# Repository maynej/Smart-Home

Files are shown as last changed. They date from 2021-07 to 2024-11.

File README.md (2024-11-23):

# Parc Mediambiental i Casa Domòtica Educativa

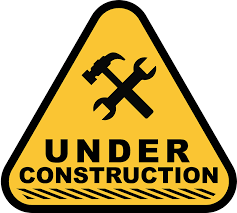
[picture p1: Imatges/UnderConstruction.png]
Parc Mediambiental en construcció 

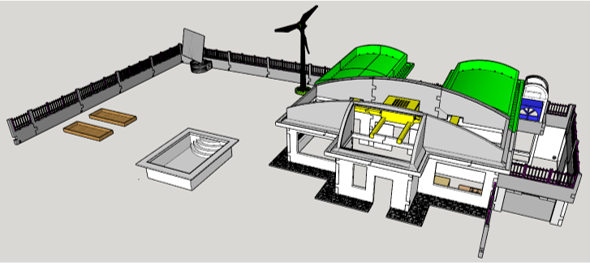
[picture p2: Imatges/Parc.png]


Casa Domòtica

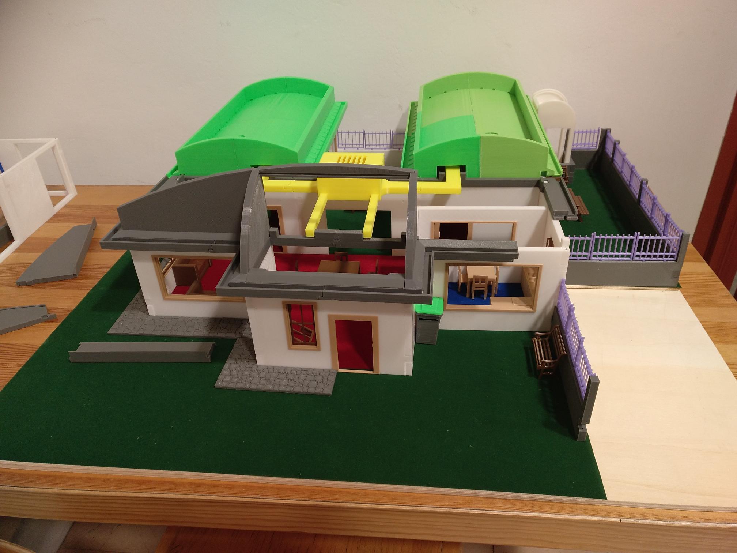
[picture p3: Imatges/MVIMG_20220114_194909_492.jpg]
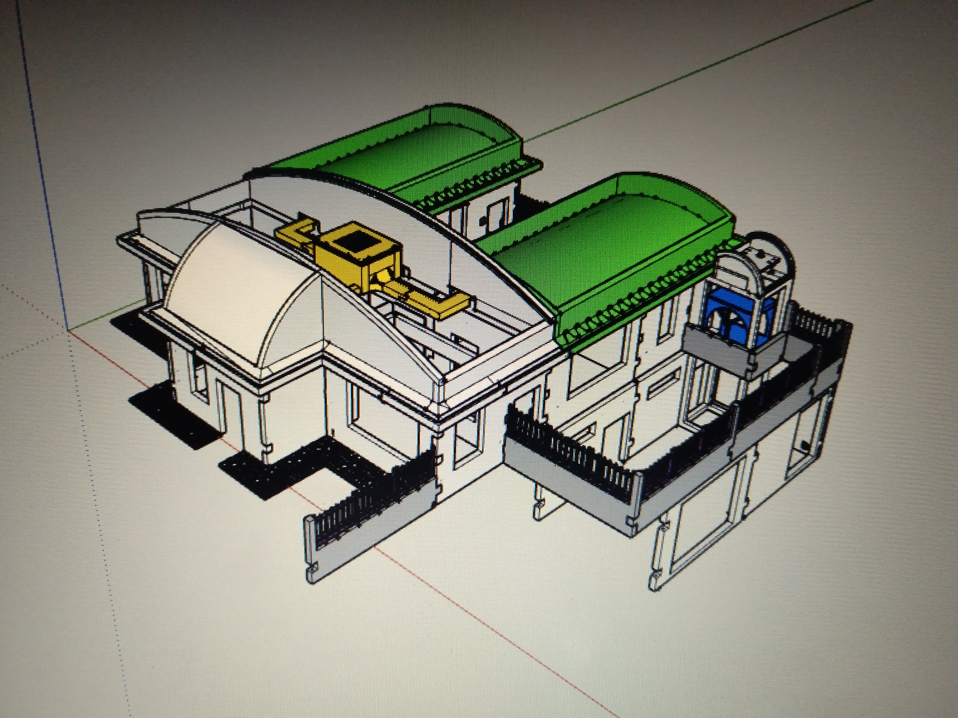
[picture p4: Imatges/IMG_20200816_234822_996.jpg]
 

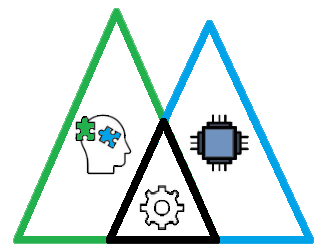
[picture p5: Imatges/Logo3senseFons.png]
Realitzada per [Jordi Mayné](https://github.com/maynej) des de Mechatronic Study jordi.mayne@mechatronicstudy.com 

L'objectiu es construir un parc mediambiental educatiu on estiguin representats espais del nostre entorn on vivim, arbres, hort, riu... i una casa sostenible aplicant la domòtica, gestionant el medi ambient i mesurant paràmetres de la natura.

Tota la [documentació es pot trobar en PDF](https://github.com/maynej/Smart-Home/tree/main/DOC). També en llengua castellana.

Un vídeo del muntatge de l'estructura de la casa el podreu trobar en la carpeta [Vídeos](https://github.com/maynej/Smart-Home/tree/main/Videos)

STL per imprimir [aquí](https://github.com/maynej/Smart-Home/tree/main/STL_SMARTHOME).

## Casa 3D 
  
Descripció         | Imatge          | Arxiu         
------------- | ------------- | ------------- 
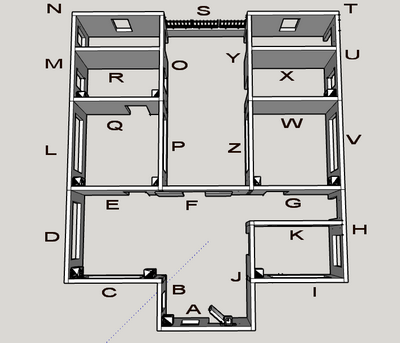
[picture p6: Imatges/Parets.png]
Parets | | [Parets](STL_SMARTHOME/Casa/Parets)
Finestres | | [Finestres](STL_SMARTHOME/Casa/Finestres)
Portes | | [Portes](STL_SMARTHOME/Casa/Portes)
Ascensor | | [Ascensor](STL_SMARTHOME/Casa/Ascensor)
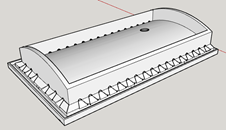
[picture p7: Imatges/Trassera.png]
Teulades |  | [Teulades](STL_SMARTHOME/Casa/Teulada)
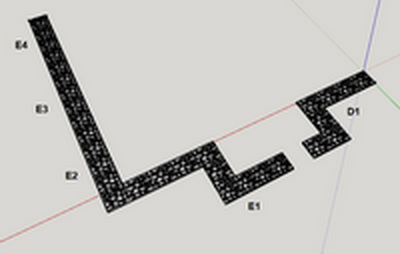
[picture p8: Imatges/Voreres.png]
Voreres | | [Voreres](STL_SMARTHOME/Casa/Vorera)
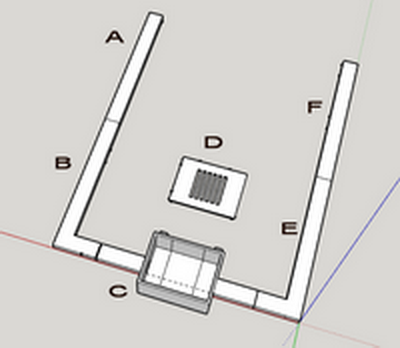
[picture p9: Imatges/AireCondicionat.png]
Aire Condicionat | | [Aire Condicionat](STL_SMARTHOME/Casa/AireCondicionat)
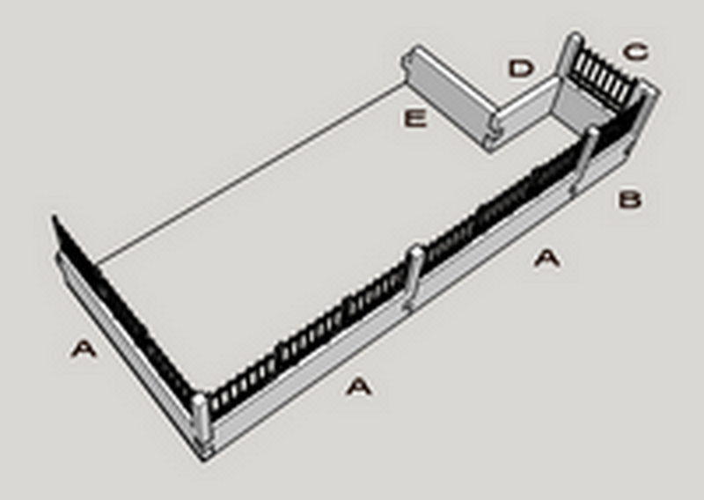
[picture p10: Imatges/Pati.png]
Pati | | [Pati](STL_SMARTHOME/Casa/Pati)

## Garatge

Descripció         | Imatge          | Arxiu         
------------- | ------------- | ------------- 
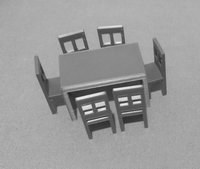
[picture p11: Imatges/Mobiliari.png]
Mobiliari | | [Mobiliari](STL_SMARTHOME/Casa/Mobiliari)

## Garatge

Descripció         | Imatge          | Arxiu         
------------- | ------------- | ------------- 
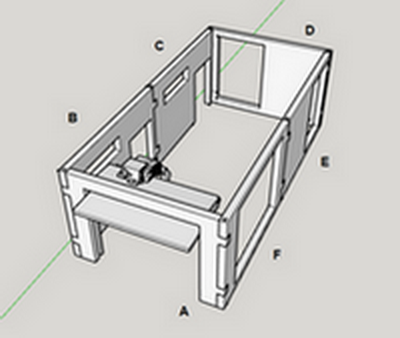
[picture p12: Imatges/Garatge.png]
Garatge | | [Garatge](STL_SMARTHOME/Garatge)

## Jardi (en contrucciò)

Descripció         | Imatge          | Arxiu         
------------- | ------------- | ------------- 
Generador Eòlic | | [GeneradorEolic](STL_SMARTHOME/Jardi/GeneradorEolic)
Seguidor Solar | | [SeguidorSolar](STL_SMARTHOME/Jardi/SeguidorSolar)

## Llicència

Creative Commons Attribution-NoComercial-ShareAlike 4.0 International (CC BY-NC-SA 4.0)  

## QR
<div id="qrcode">
Generador de Códigos QR Codes
<br/><a href="https://www.codigos-qr.com/en/qr-code-generator/" target="_blank" id"qrgenerator">Qr Code Generator</a>
</div>

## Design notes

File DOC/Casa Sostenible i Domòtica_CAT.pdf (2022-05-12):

1 | JORDI MAYNE ‐ 2022

# Parc mediambiental i casa domòtica sostenible

## Objectiu

Construir un parc mediambiental educatiu on estiguin representats espais del nostre entorn on vivim, arbres, hort, riu... i una casa sostenible aplicant la domòtica, gestionant el medi ambient i mesurant paràmetres de la natura.

## Dinàmica educativa

- Es pretén que sigui Obert, Didàctic, Evolutiu, Modulable, Flexible, i de baix cost.
- La construcció de la maqueta està preparada per ser impresa en una impressora 3D convencional, però, es pot fer amb fusta o cartró ploma, i al ser modular permet adaptar‐la a les necessitats.
- Permet gestionar els llums a LED de colors, Sensors, Actuadors y altres elements electrònics per tal fer la part domòtica i gestió que es podrà controlar amb un Arduino, Microbit o Rasberry ...

Com es podrà veure en tota la descripció, es vol que es puguin explorar el màxim tipus d’elements i tecnologies

## Descripció general

### Generació d’Energia

La generació d’energia es un dels punts d’estudi i aplicació en la maqueta: Eòlica, Solar, Tèrmica, Geotèrmica, Hidràulica

### Sensórica Externa

Mesurar paràmetres del nostre entorn ajudarà a gestionar‐lo, com la Temperatura i Humitat ambient, Humitat del sòl, Pressió atmosfèrica, Llum, Color, Raigs ultraviolats, Qualitat del aire i aigua, Nivells d’aigua, Velocitat i direcció del vent, Partícules en el aire.

### Casa Domòtica

Control del màxim d’elements fent servir tecnologies diverses com la Llum, Accés, Tendal, Ventilació, Calefacció, Motors, Vàlvules, Intrusió, Panells Fotovoltaics, Tèrmics, Acumuladors energia.
Es detectarà Gas, Foc, Llum, So, Humitat, Temperatura ambient, Temperatura del aigua, Presencia (PIR, IR), Alarma, Intrusió.

### Comunicacions

Dintre d’un entorn sostenible les comunicacions son necessàries si es gestionen be com Bluetooth, Wifi, Ethernet, RFID

## Realització del projecte

- Descripció de cada part de la maqueta.
- Selecció de materials i components.
- Desenvolupament de cada part.
- Construcció de la maqueta.
- Composició del control electrònic.
- Control global de la maqueta.

### Maqueta

La maqueta es divideix en dues parts, una es la Casa pròpiament i l’altre el seu entorn que l’anomeno Parc, degut a les dimensions de la mateixa, uns 80x85cm cada part. Això comença a definir la modularitat d’aquest projecte. Seguidament es descriu cada una de les parts.

## Parc mediambiental

### Estació Meteorològica

- Peces fetes amb una impressora 3D ja dissenyades a Thingiverse, hi ha moltes possibilitats.
- No podrà tenir unes dimensions proporcionals a la maqueta de la casa per la pròpia física.
- Estarà situada en la part oposada a la casa per millorar la seva perspectiva.
- Comunicarà via radio (Wifi o Bluetooth) amb la central de control de la casa, on una pantalla mostrarà totes les dades.

(Estació metereológica)

Opció 1: Mòdul GY‐39 Intensitat de llum MAX44009 + BMP280 Temperatura, Humitat, Pressió

Opció 2: GY‐30 (Intensitat llum) o GY302 o GY‐49 (Intensitat llum) MAX44009,
BMP280 (Pressió, Temperatura), DHT11 (Humitat, Temperatura) Mòdul Wifi ESP 32

Velocitat del vent (contactes reed + imant)
Direcció del vent (reed + imants) Pluviòmetre (reed + imant)

### Hort i Arbres

Un recipient ple de terra farà d’hort, es mesurarà la humitat de la terra i juntament a la temperatura i la llum es programarà el regadiu.

(Hort)

### Generació d’energia

Panell Foto‐voltaic amb seguidor solar per generar electricitat
- https://www.thingiverse.com/thing:4056888
- Cèl∙lula Solar 5V
- Motors servo MG90.
- Cèl∙lula LDR | (Panell Solar)

Panell Tèrmic per escalfar aigua
- Tub en espiral formant un panell solar, anirà en el terreny del costat de la casa.
- L’aigua calenta entra en un dipòsit acumulador de la casa
- Sensor de temperatura
(Panell Tèrmic)

Aprofitament Geotèrmic
- Tub en espiral sota terra amb una Peltier per simular el comportament subterrani
- Tub en espiral en el terra de la casa
- Sensor de temperatura | (Aprofitament Geotèrmic)

Generador Eòlic per generar electricitat
- https://www.thingiverse.com/thing:1767153
- Dinamo: motor dc 15.2 x 19.8 mm, rotor 2 mm.

(Generador Eòlic)

Generador Hidràulic per generar electricitat
- Un dipòsit superior configura un canal d’aigua fins un salt on fa moure les pales del generador, segueix l’aigua a un petit llac, que deriva a un canal més petit per regar el hort i arbres.
- https://www.thingiverse.com/thing:802284
- Salt d’aigua amb dinamo: motor dc 15.2 x 19.8 mm, rotor 2 mm.
(Turbina d’aigua)

Casa Sostenible i Domòtica • Les noves cases han de ser sostenibles, aprofitant totes les energies renovables que estiguin a l’abast

(eòlica, tèrmica, solar, hidràulica, geotèrmica).
- Recollida de l’aigua pluvial per reaprofitar‐la.
- Aprofitament de la llum solar i el vent.
- Aïllament amb un sostre verd.
- Control de residus.
- Control domòtic.

### Disseny de la maqueta de la casa

Per fer la maqueta vaig buscar idees i maquetes fetes amb impressió 3D. Només vaig trobar a Thingiverse aquesta https://www.thingiverse.com/thing:2364628 que em va semblar una bona forma d'assemblar les parets i les dimensions (escala 1:24), per poder incloure i manipular els actuadors, encara que l’he transformat i adaptat a les necessitats buscades.

(1)

La maqueta s’ha dissenyat per cobrir totes les necessitats per aplicar tecnologia. Primer dibuixant tota la casa , que al final te unes dimensions importants 850x800mm i desprès feta a trossos per poder‐la imprimir en una impressora 3D convencional de 200x200mm i d’aquesta manera es pot tractar de forma modular i realitzar amb els mateixos mòduls altres tipus de configuració de la casa. També incorporen les fixacions dels actuadors a les portes, finestres, i allotjaments dels llums. La teulada es pot treure molt fàcilment per mirar i accedir a l’interior de la casa.

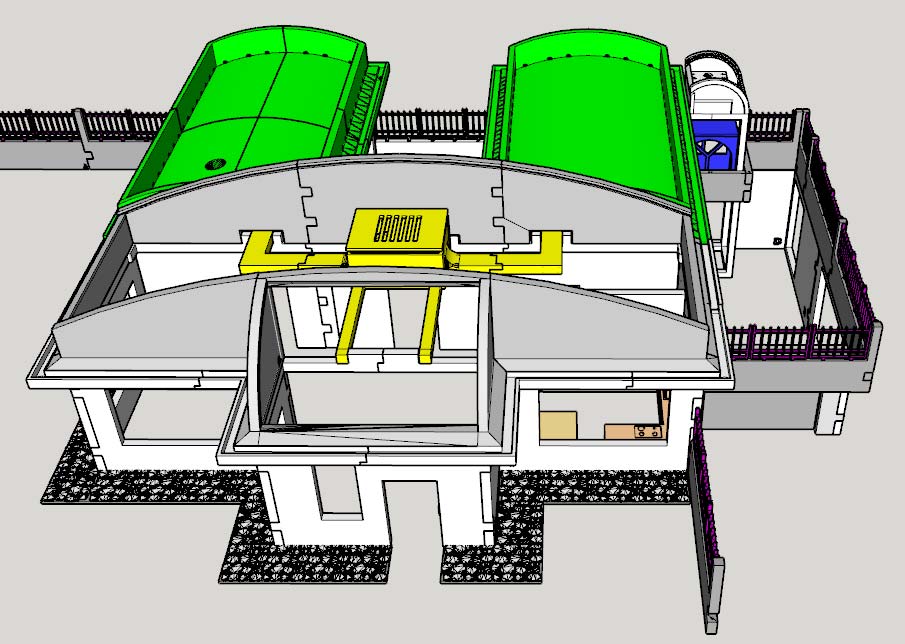
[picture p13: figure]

(2)

### Identificació i unió de les peces de la maqueta

- Per fer la maqueta s’ha buscat un sistema d’identificació de cada peça, marcant amb una lletra cada paret o mur per un construcció guiada i més fàcil.
- La unió entre les peces s’han dissenyat per que no estigui que fer servir cap cola en la majoria de les peces. Aquesta unió està feta a base d’encaixos i un passador que les fixe.

## Descripció de l’exterior Casa

- Casa de tipus unifamiliar que sigui accessible per manipular els diferents components.
- Porta per vehicles exterior motoritzada per anar al garatge. Accés via Bluetooth.
- Porta d’accés a la finca. Timbre, i Accés amb identificació RFID.
- Il∙luminació autònoma a LED, amb detecció de presencia i de llum diürna.

### Porta d’entrada de vehicles

Porta lliscant amb accés remot via Bluetooth per identificar i obrir.

- Mecanisme cremallera amb servo‐motor de 360 graus MG995.
- Identificació via Bluetooth HM10 o Wifi relé ESP8266
- Llum de senyalització de moviment de porta APA106 o WS2812.
- Verd detecció ID Bluetooth
- Ambre moviment porta
- Vermell Identificació invàlida
- Detecció d’obstacles de seguretat amb IR TCRT5000 | o HCRS04 .

### Porta d’accés a la finca

Com qualsevol casa un polsador servirà de timbre, també un lector RFID identificarà i permetrà obrir la porta amb una targeta RFID vàlida.

- Timbre de trucada amb polsador
- Lector RFID RC522
- Porta motoritzada amb Servomotor SG90

### Il∙luminació exterior de la casa

Llums LED de color WS2812 i un sensor de proximitat PIR HC‐SR501 amb sensor de llum diürna per il∙luminar la porta d’entrada o les permanents de nit des del control central.

### Dipòsit d’aigua pluja

L’aigua de pluja es recull des de la teulada de la casa, s’emmagatzema en un dipòsit intern per fer servir per lavabos, dutxa, wc, rentadora.

- El sistema de control de bombeig.
- Control de nivell dipòsit d’aigua.

## Descripció de l’interior de la Casa

- Control d’accés portes exteriors
- Sistema d’alarma
- Control de llum LED individualitzat amb intensitat i color
- Guia llum solar recolzada amb LED
- Control finestres batents motoritzades
- Control de portes motoritzades
- Control Ventilació, Calefacció, Refrigeració
- Ascensor
- Tendals motoritzats

### Porta d’accés a la casa

- Lector RFID RC522 | Lector Empremta dactilar
- Servo SG90

### Llum interior de la Casa

El control de la llum tant es fa manualment, com automàtic mitjan sensors.

- LED + Detector IR per passadissos HC‐SR501
- LED + Interruptor sensitiu per saló TTP223
- LED + Sensor de veu per la despensa
- Led + Sensor de llum ambiental TEMT6000 | o LDR

### Guia llum solar

Cilindre de metacrilat guia la llum solar en el interior de la casa, per la nit un llum LED fa la funció solar

(6)

(5)

### Control de tendal

- Tendal o Persiana, Sostre motoritzat
- Motor pas a pas K976
(7)

### Aire Condicionat

Un sistema central d’aire condicionat format per una cèl∙lula Peltier genera calor o fred per inversió de polaritat, i un ventilador mou l’aire per tota la casa

- Temperatura LM35 | o DS18B20
- Ventilador + Peltier (Refreda/Escalfa)

### Sistema d’Alarma

Un sistema integrat d’alarma contra intrusió, foc, gas

- Sensor de vibració SW‐520D
- Contactes amb imants a finestres
- Sensor de gas MQ‐2
- Sensor flama
- Brunzidor

### Pantalles de control

- Pantalles Oled o LCD, on es distribuirà la informació per treballar per àrees. També es podrà tindre accés des de un telèfon o “tablet”.
- Monitorització de dades de l’estació meteorològica.
- Monitorització del control d’accés a la casa, garatge, sistema de seguretat.
- Monitorització de la refrigeració, ventilació, calefacció
- Monitorització del ascensor.

### Sistema central de control

El control també està pensat obert, si no ja no seria didàctic. Tots els actuadors i sensors poden estar adaptats a les plataformes més utilitzades com Arduino, ESP32, Microbit o Raspberry.

El software d’aquestes plataformes permeten utilitzar diferents llenguatges de programació, Scratch, C++ per Arduino, ArduinoBlocks, MakeCode, Python entre d’altres.

- Arduino, ESP32: Scratch, Arduino Blocks, C++
- Microbit: MakeCode, Python, C++
- Raspberry: Python, Java, Linux

Alimentació i bateries.

La maqueta al igual que moltes cases actuals que generen energia per el autoconsum, necessiten també d’energia elèctrica addicional. La maqueta tindrà generadors d’energia que carregaran unes petites bateries i també tindrà un font d’energia addicional.

Plantejament de la casa Com que no soc arquitecte segur que no he fet una casa "bonica“, ni arquitectònicament correcte, però tinc

la sort de tenir amistats arquitectes que m’han ajudat a fer algunes correccions.

El que busco es aplicar diferents tecnologies per fer una casa sostenible, aprofitant les energies renovables i fer conscienciació dels nostres elements que ens envolten.

El garatge sota terra es justifica per poder tenir un ascensor amb el seu control. I a més poder tenir sota la casa el cablejat de control totalment manipulable, el dipòsit de recollida d'aigua de pluja i el dipòsit tractament d'aigües blaves.

L'accés als dispositius tant de la casa com a la resta del entorn es accessible, per poder veure o canviar els sensors, actuadors o sistema de control de qualsevol racó.

## Plantejament del control

- El control es podrà fer a través de tasques individualitzades o agrupades junt amb la pantalla o pantalles per mostrar els seus funcionaments o/i amb un control central per recollir el funcionament global.
- Moltes tasques es faran simulades intentant reproduir al màxim el seu funcionament real.
- Els sensors bàsics utilitzats es podran canviar per altres més cars o sofisticats, està previst que el seu accés i cablejat ho permeti.
- Els actuadors seran alguns diferents per provar totes les tecnologies.

Aquest apartat es mostrarà al final de la construcció de la maqueta

### Maqueta interior casa

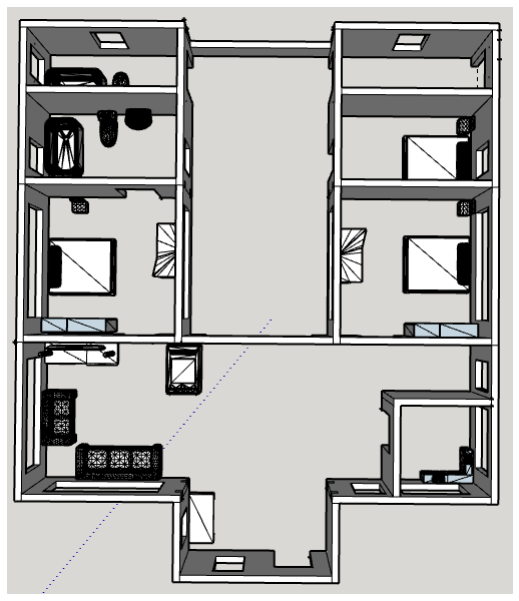
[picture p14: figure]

(8)

### Maqueta Casa, Garatge i Pati

El pati està a sobra del garatge i deixa un espai per el pas del ascensor.

### Maqueta Garatge i Ascensor

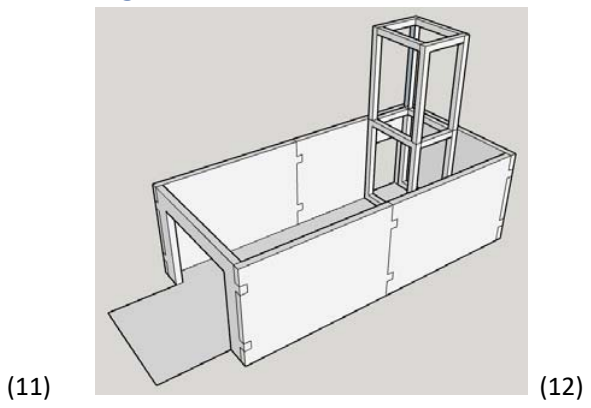
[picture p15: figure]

Detall del mecanisme de la porta de garatge

(13)

### Ascensor

L’ascensor te dues plantes. Permet accedir a la casa des del garatge.

- Un motor pas a pas en la part superior proporciona un desplaçament precís i lent. 28BYJ‐48 DC 5V
- La cabina te dues guies, una llisa i una amb rosca M4

(14)

### Finestres batents i Portes motoritzades

- Les finestres son batents amb moviment a través d’un servo‐motor.
- Les portes també estan motoritzades a través d’un servo‐motor.
- Totes les portes i finestres tenen els ancoratges en la paret per posar un servo‐motor.

### Aire Condicionat

- Una màquina en el saló distribueix l’aire, aire fred i aire calent.
- Un ventilador de 40x40x10 impulsa aire que passa per una cèl∙lula Peltier. Canviant la polarització de la Peltier produeix fred o calor.
- Els tubs condueixen cap a totes les estàncies.

(16)

### Teulada

La teulada està formada per tres parts, la frontal i els dos posteriors. Amb una base amb els canals de desguàs del l’aigua pluvial, i per la part de sota incorpora els espais on aniran instal∙lades les llums externes a LED.

- Teulada Frontal
La teulada frontal serà transparent i amb una
coberta interior tèxtil motoritzada per aïllament
tèrmic.
Permet observar l’interior del menjador/sala i cuina

(17)

- Teulada Verda
La teulada verda dels dos laterals permeten drenar l’aigua i formar un aïllament tèrmic, així com un entorn visual millor.

Per sota hi ha els allotjaments dels llums d’habitacions i exteriors, i el canal dels fils, perquè es pugui treure la teulada de la maqueta per accedir a l’interior.
El forat rodó permet instal∙lar un guia llum.

(18)

La coberta de la teulada estarà coberta de verd, amb plantes i diferents capes de materials que permeten un aïllament de la casa i drenar l’aigua de pluja.

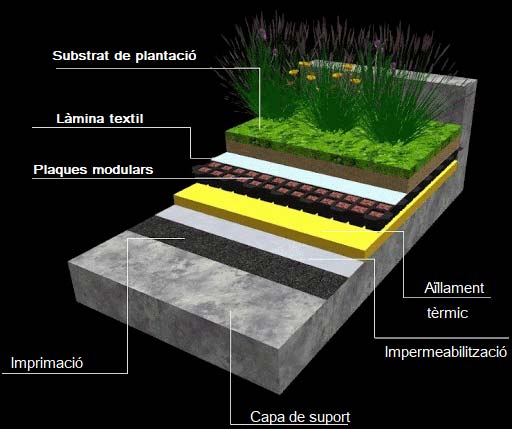
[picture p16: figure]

(19)

- Teulades a la maqueta

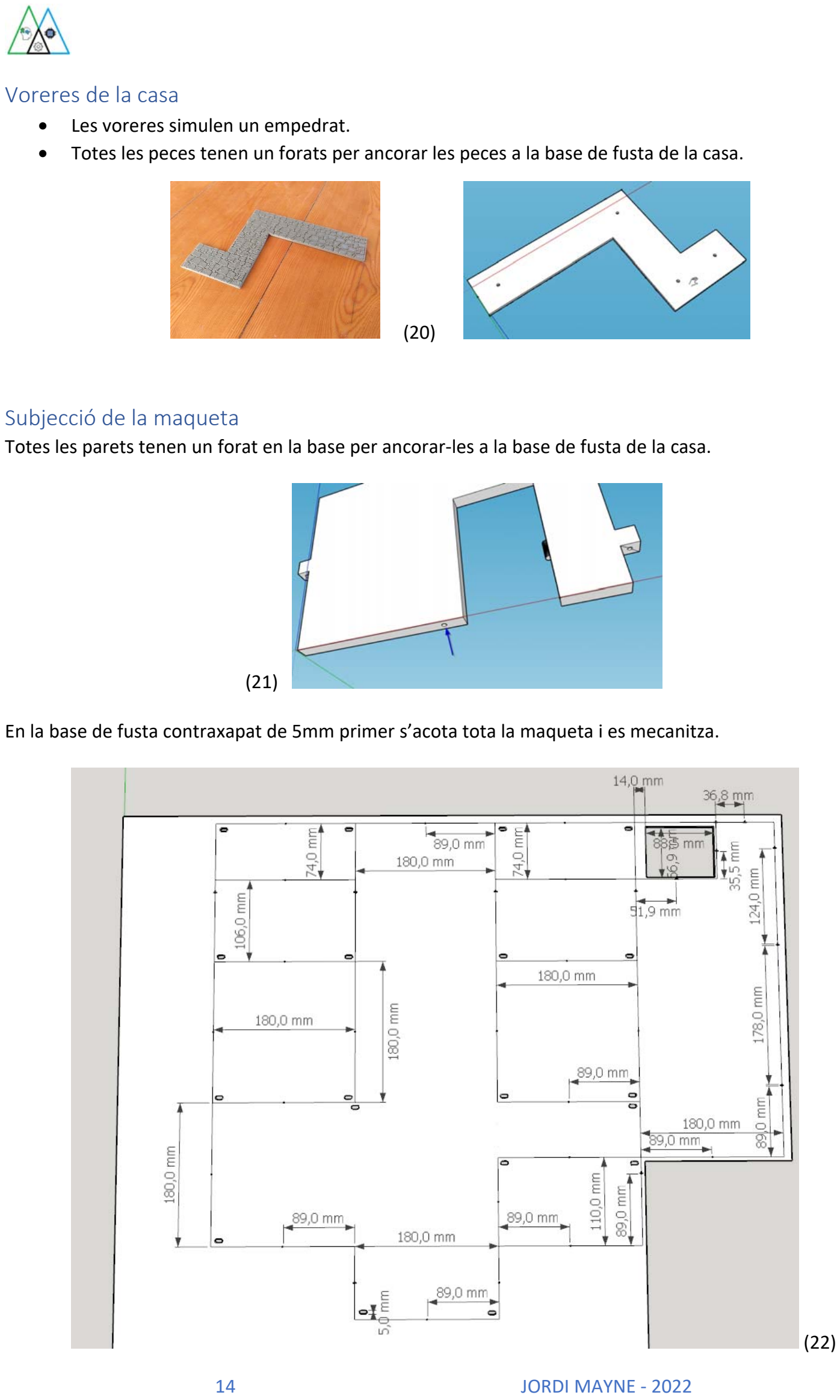
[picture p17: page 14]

### Voreres de la casa

- Les voreres simulen un empedrat.
- Totes les peces tenen un forats per ancorar les peces a la base de fusta de la casa.

(20)

### Subjecció de la maqueta

Totes les parets tenen un forat en la base per ancorar‐les a la base de fusta de la casa.

(21)

En la base de fusta contraxapat de 5mm primer s’acota tota la maqueta i es mecanitza.

(22)

Abans de fixar‐la s’aprofita per emmoquetar el terra del interior i la gespa del exterior.

Seguidament ja es pot fixar la maqueta

Ara ja es pot continuar treballant amb la resta de la casa, posant els marcs de les portes, finestres, ....

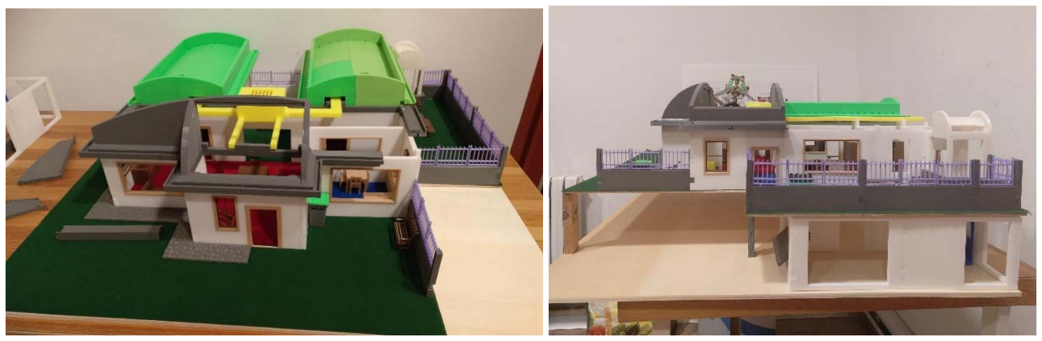
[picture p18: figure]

El tauler base de la casa es pot muntar sobre un altre tauler de 10mm contraxapat, separat per columnes de 120mm d’alçada, que es la mida exacte del garatge. Aquest espai servirà per col∙locar l’alimentació, bateries, electrònica, displays, lectors RFID i lector dactilar, etc ...

La teulada semi‐transparent es pot fer amb full de plàstic a partir de 0,75mm de gruix per que tingui una mica de consistència. S’ha de tallar per la teulada frontal 176x132mm i la per la teulada del saló/menjador/cuina amb dos trossos de 176x290.

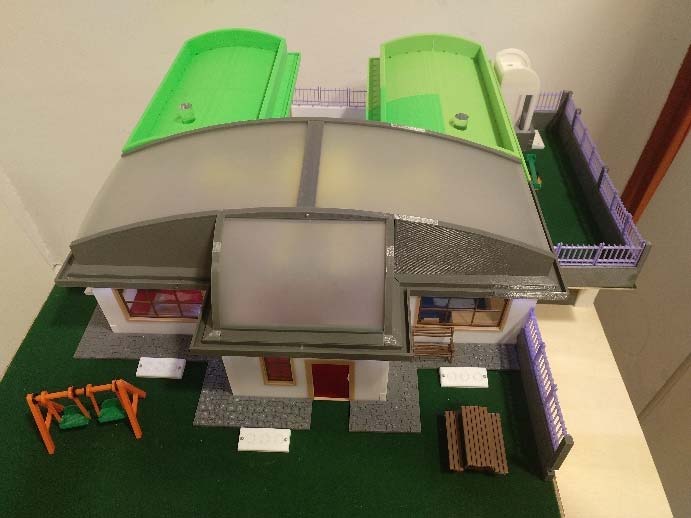
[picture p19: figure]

### Muntatge electrònic

Per començar amb el sistema electrònic es pot fer el connexionat dels llums de LED multicolor WS2812B en la part posterior de les teulades. Fent servir tres fils (Positiu 5V,
negatiu (gnd) i dades) amb tres color ben diferenciats per no fer cap errada, es poden fixar
els fils trenant en forma d’espiral i subjectats amb tub termo‐retràctil.

Les soldadures han d’estar ben fetes i que no puguin creuar les connexions, cal fer una revisió visual abans de col∙locar‐lo als encaixos de la teulada i una prova de funcionament.

Una vegada que es te el cablejat fet, es col∙loca en la guia corresponent i es fixe amb una mica de cola termo‐ fusible.

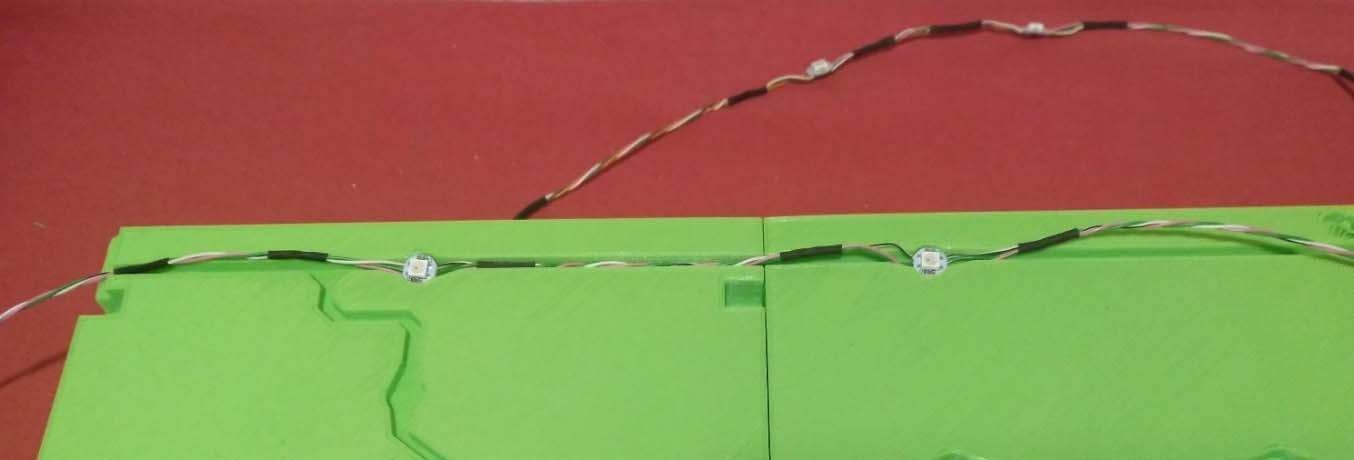
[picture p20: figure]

## Plantejament del control

Tal com està exposat al principi d’aquest document, el control es podrà fer a través de tasques individualitzades o agrupades per facilitar una programació primerament per parts i també per facilitar l’ús de un hardware senzill. D’aquesta manera es poden establir funcionalitats bàsiques fins les més complexes, i funcionalitats futures.

### Tasques individualitzades

En aquest apartat es mostraran les tasques que es poden realitzar per treballar‐les individualment i el seu hardware associat.

### Control dels llums de la casa

Els llums de la casa son de LED del tipus RGB WS2812, que permeten encendre amb el color que es vulgui (per programa), així com amb la intensitat de llum desitjada. Això permet també fer escenaris diferents sobre tot amb la il∙luminació exterior. I en el interior també poder fer servir per fer un ambient més càlid per les habitacions o més fred com potser la cuina. Aquets llums poden ser automàtics com el cas dels llums exteriors, amb un sensor de llum ambient, o a través de polsadors tàctils a cada habitació. També es podrà comandar algun llum amb sensor de presencia, com pot ser en el passadís de l’ascensor, ascensor i garatge. Per tant si es fa flexible la instal∙lació d’elements de control donarà més marge d’usar més mitjans de control i de futures idees.

Primer de tot cal enumerar cada punt de llum de la casa.

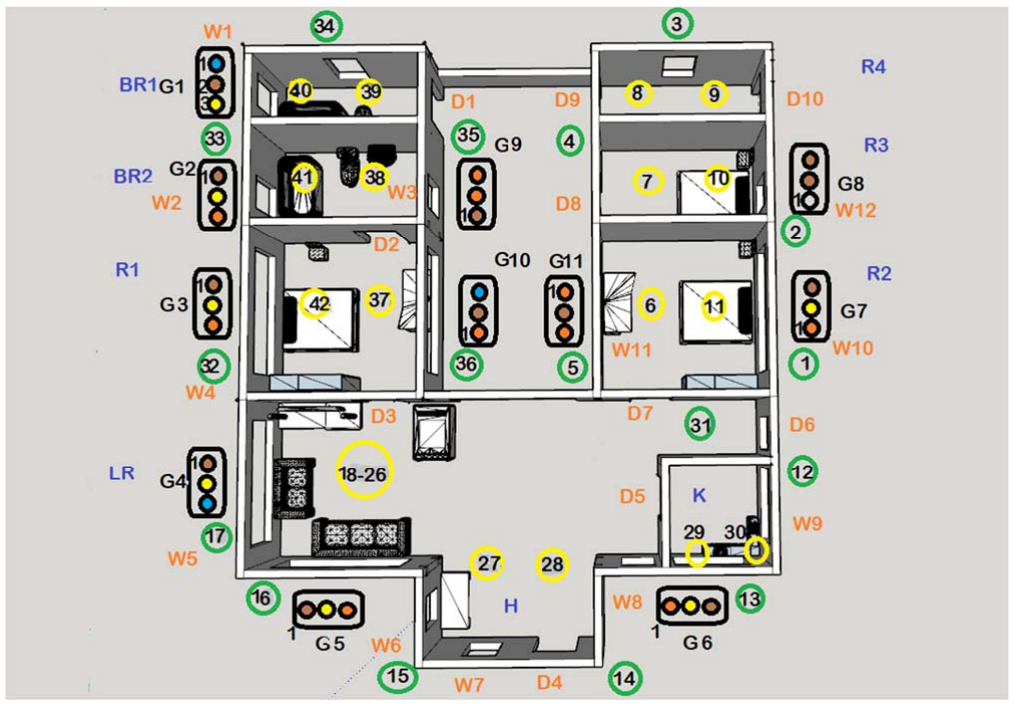
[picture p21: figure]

Els cercles de color verd son els llums d’exterior de la casa, que normalment es faran encendre tots a la vegada i amb el mateix color tots, però es podran programar escenes amb diferents colors e intensitats de llum. En color verd també hi han els llums externs, però, de
la terrassa interior, aquest agrupament es pot fer separadament dels altres amb un color
fixe. Els cercles de color groc son part de la il∙luminació interior, saló‐menjador, cuina,
dormitoris banys i passadissos. Aquests llums tenen els punts d’encendre senyalitzats com a G1, grups de 3 polsadors que poden actuar com polsador o interruptor numerats com G1_1, G1_2, G1‐3. També es faran servir aquests polsadors tàctils per obrir i tancar finestres com W1 o portes com D1. Finalment també s’enumeren els espais com BR1, BR2, R1...

Tots aquests punts de llum a LED van connectats en sèrie en el ordre indicat de numeració, i s’utilitzen 3 fils (positiu, negatiu i dades), aquets fils aniran connectats a la placa de control que es posi (ja sigui Arduino, Microbit,...) i fa que només ocupi un pin de sortida.

### Polsadors/Interruptors

En la maqueta hi ha punts de polsadors per activar llums, servos, aquests polsadors son tàctils utilitzant el TTP223, un circuit que permet diverses maneres de treballar, com un polsador, com un interruptor. Encara que te altres funcionalitats.

Les particularitats d’aquest circuit que es mostra en l‘esquemàtic, es que pot alimentar entre 2,5 a 5Vdc i directament entrega un estat de sortida depenent de les connexions dels pins A i B, un LED indica l’estat de sortida.

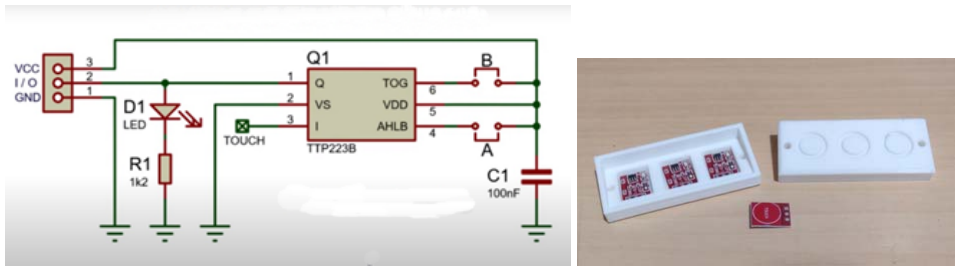
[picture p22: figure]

Connexionat | Acció
Sense B | Polsador
Pont B | Interruptor
Pont A | Nivell alt per defecte

El connexionat del polsador tàctil tindrà una connexió del pont B, per tenir funcionalitat Polsador o Interruptor segons el vulgui programar. Estarà disponible en la part inferior de la casa un connector pont.

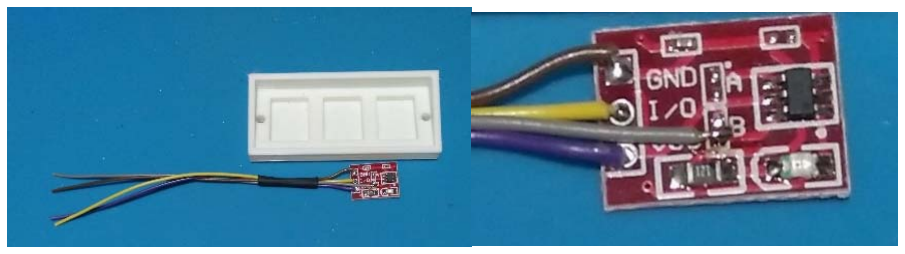
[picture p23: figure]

Així quedaria el connexionat amb la placa Arduino, però ja es veu que utilitza molts pins d’entrada.

### Expansió d’entrades i sortides en un Arduino

Com que es necessiten moltes entrades de polsadors els llums i servos, cal plantejar utilitzar varies plaques Arduino, cosa que no es la solució més adequada. Es millor col∙locar un expansor d’entrades que es pot fer amb un mòdul placa multiplexor analògic o amb un mòdul expansor I2C.

74HC4067 multiplexor de 16 canals, s’alimenta entre 2,5V a 6V, permet fins a 16
canals (C0 a C15) d’entrada o sortida i es necessiten 3 senyals de control (S1 a S3),
dos pins alimentació, un de Enable.

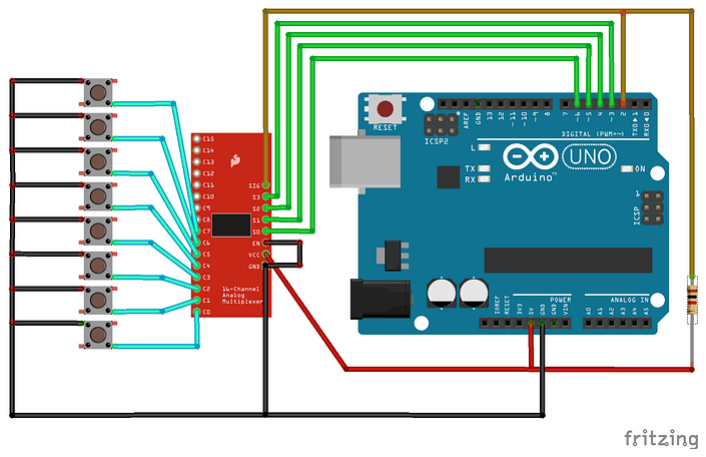
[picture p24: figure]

Però, no es la millor solució en quan a consum i número de fils cap al microcontrolador.

Una solució més avançada es utilitzar un circuit que es comunica amb el microcontrolador amb 2 fils, via I2C.

PCF8574 es un expansor de 8 canals digitals de entrada/sortida amb comunicació I2C cap el microcontrolador, per defecte al alimentar el circuit son entrades digitals (P0 a P7), funciona entre 2,5 i 6V, incorpora 3 pins (A0 a A2) per configurar l’adreça I2C (des de 0x20 a 0x27), te dos pins de comunicació típiques de I2C, SDA (dades), SCL (rellotge) i un pin INT (interrupció) que es posa a nivell 0 quan hi ha un canvi de flanc en algunes de les entrades/sortides del xip, això permet no tenir que rastrejar constantment els pins d‘entrada per part del microcontrolador.

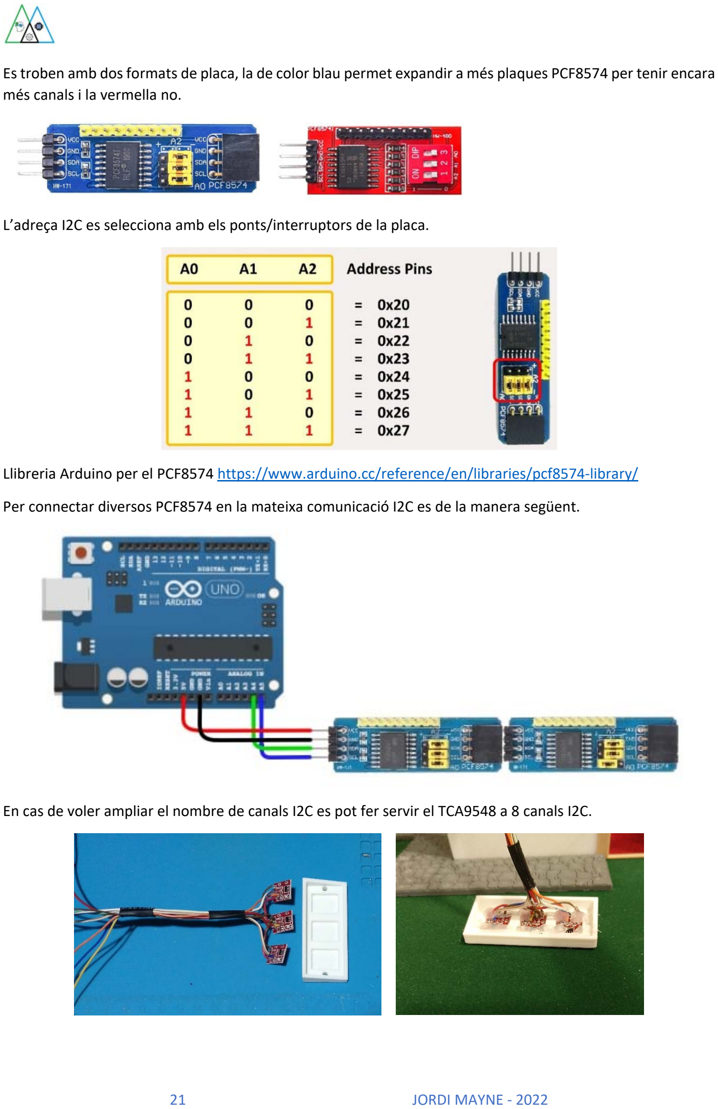
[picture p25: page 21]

Es troben amb dos formats de placa, la de color blau permet expandir a més plaques PCF8574 per tenir encara més canals i la vermella no.

L’adreça I2C es selecciona amb els ponts/interruptors de la placa.

Llibreria Arduino per el PCF8574 https://www.arduino.cc/reference/en/libraries/pcf8574‐library/

Per connectar diversos PCF8574 en la mateixa comunicació I2C es de la manera següent.

En cas de voler ampliar el nombre de canals I2C es pot fer servir el TCA9548 a 8 canals I2C.

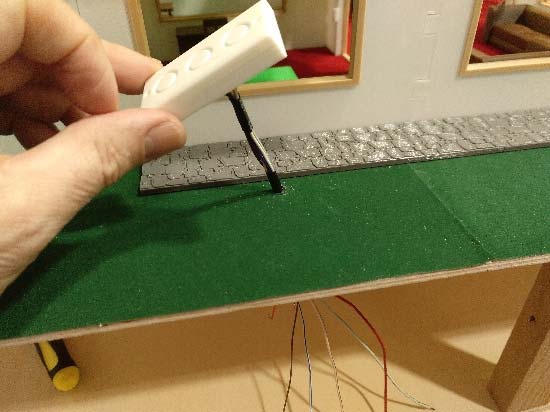
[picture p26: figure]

Es pot observar que a través de la coberta de plàstic es pot veure la llum vermella de actuació del tàctil.

### Control de 16 servomotors en un Arduino

Com que es necessiten moltes sortides per tots els servomotors de control de portes i finestres; Arduino només disposa de 6 sortides PWM, per el que cal utilitzar varies plaques, però, no es la solució més adequada. Es millor utilitzar una placa PCA9685 connectada via I2C amb el microcontrolador.

A més els servomotors tenen un consum elevat, sobre els 200mA multiplicat per 16 son 3,2A

PCA9685 suporta fins a 16 servomotors controlats via I2C, disposa del
pins per connectar adequadament els servomotors, les adreces I2C
van des de 0x40 fins a 0x7F soldant els ponts (A0...A5), entrega 16
sortides PWM de 12 bits, s’alimenta a 5V, i les línies SDA i SCL de I2C son compatibles 3V3 o 5V.

Servomotors SG90

Un servomotor o anomenat també servo, és un motor DC amb la capacitat posar el seu eix en una posició o angle determinat, internament té una caixa d’engranatges reductora que fa augmentar el parell motor i redueix la velocitat, un potenciòmetre està encarregat de sensar la posició de l’eix i junt amb una electrònica formen un control de llaç tancat.

Hi ha diferents tipus de servo‐motors, el més utilitzat es el SG90 que es suficient per la majoria d’aplicacions. Funciona entre 3 i 7.2V, te un parell motor entre 1 i 1.6 kg/cm. Altres tenen parells motor més grans arribant fins a 15 kg/cm.

Base per programar els servomotors

https://www.luisllamas.es/controlar‐16‐servos‐o‐16‐salidas‐pwm‐en‐arduino‐con‐pca9685/

Informació per més coneixement sobre els Servomotors:

https://dronprofesional.com/blog/tutorial‐teorico‐practico‐con‐servos‐y‐arduino/

Esquemàtic de control de llums i servos

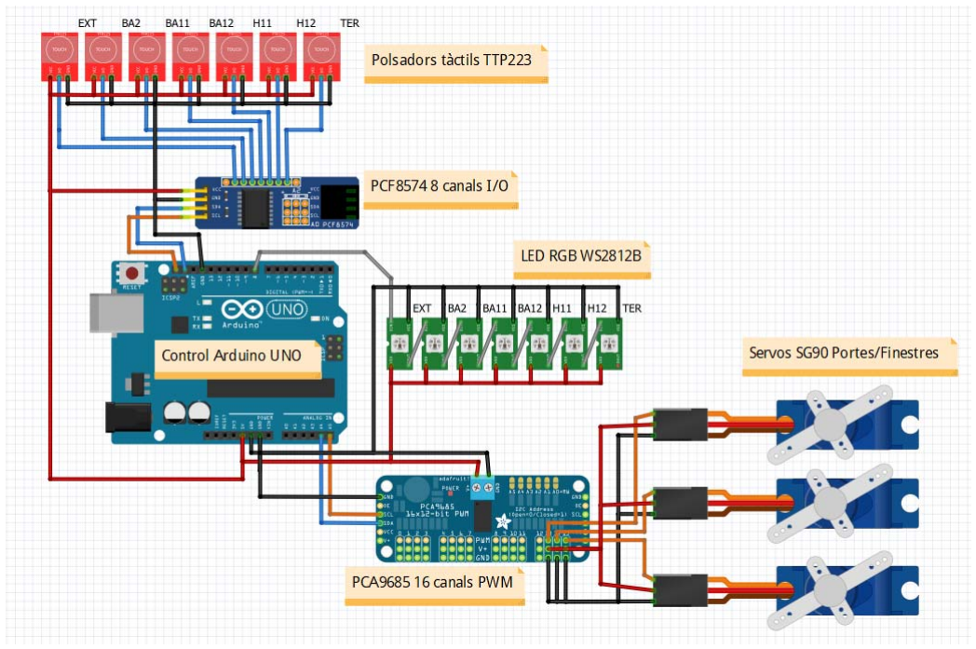
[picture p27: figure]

Muntatge del servo motor en un suport i la fixació a la paret d’una finestra i d’una porta.

### Sensor de llum ambient

De sensors de llum hi ha diverses possibilitats: el TEMT6000 que només detecta la presència amalgamada de llum amb longituds d'ona en el rang de 390 a 700 nm. Es troba amb formats molt petits, com el Lilypad o format rectangular per poder‐lo fixar.

Lilypad | Rectangular

El TSL2561 es un sensor de lluminositat que pot detectar tant la llum visible com la llum infraroja. El ISL29125 es un sensor de llum RGB que pot detectar llum específicament vermella, verda, blava o qualsevol combinació d'aquestes. El ML8511 es un sensor de llum U,V funciona de manera similar al TEMT6000, però respon a la llum ultraviolada en lloc de la llum visible. El LDR és una alternativa molt petita al TEMT6000, però és una fotoresistència (una resistència que canvia en funció de la presència de llum) en lloc d'un fototransistor.

Per això, el sensor de llum ambiental TEMT6000 és el escollit. Es un sensor analògic, compatible amb microcontroladors que admeten l'entrada de dades analògiques. Si la llum és molt baixa, el pin SIG tindrà un valor molt baix, a mesura que augmenta la llum, el pin SIG també augmentarà de valor. A més és sensible a l'espectre visible i es fa servir en molts aparells com smartphones, “tablets”, càmeres i està adaptat a la resposta de l’ull humà envers la llum. Te un angle de 60 graus i s’alimenta a 5V.

Com funciona la detecció de llum

Com s'ha esmentat anteriorment, el TEMT6000 mesura la il∙luminació. Si no esteu familiaritzat amb la il∙luminació, és una mesura de la quantitat total de llum visible emesa per una font (anomenada flux lluminós mesurada en lúmens (lm) dividida per una àrea en metres quadrats (1 lx = 1 lm/m²).

Juntament amb aquestes, hi ha altres propietats de la llum que, malauradament, s'anomenen amb la mateixa arrel llatina per a la llum, de manera que pot ser difícil mantenir‐les rectes. Aquí teniu un diagrama per dilucidar les diferències:

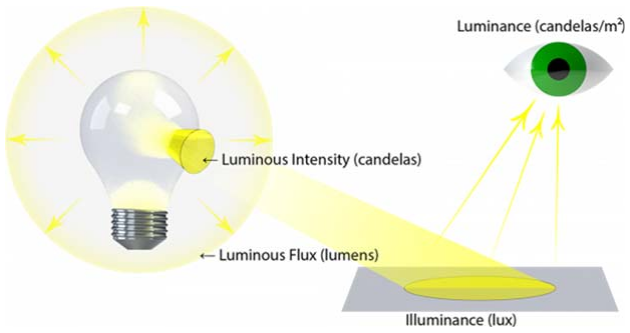
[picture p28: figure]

Per què el TEMT6000 mesura la il∙luminació? En la majoria d’assajos, mesurar la intensitat de la llum sense tenir en compte la distància és molt difícil i va deixar perplex als primers astrònoms durant molt de temps. En resum, hi ha una magnitud aparent (com de brillant sembla una font de llum) i una magnitud absoluta (com de brillant és realment la font de llum). Dues fonts de magnituds absolutes diferents poden tenir la mateixa magnitud aparent segons la seva distància a l'observador.

Per exemple, si teniu una font de llum brillant lluny i una font de llum tènue molt a prop, pot semblar que tenen la mateixa brillantor perquè la llum de la font més brillant s'haurà de dissipar en un volum d’espai més gran. És per això que el sensor llegirà un valor més petit si s’allunya de la mateixa font de llum, augmentant essencialment la quantitat d'espai que la mateixa quantitat de llum ha d'omplir entre la font i el sensor (és a dir, reduint la il∙luminació, a mesura que esteu dividint per una superfície més gran de l'esfera de llum generada per la font).

Aquí es mostra una gràfica, abstreta del TEMT600, entre el corrent (en µA) i la il∙luminació immediata percebuda pel sensor:

El TEMT6000 només reconeix la llum amb longituds d'ona en el rang de 390‐700nm, que cobreix aproximadament tot l'espectre de la llum visible. En altres paraules, això no captarà infrarojos, ultraviolats o cap altra llum que no puguem veure directament.

Aquí hi ha una taula de la il∙luminació típica de fonts comunes de llum visible:

Il∙luminació | Superfícies il∙luminades per
0.0001 lux | Cel nocturn ennuvolat i sense lluna
0.002 lux | Cel nocturn clar sense lluna amb resplendor del cel
0.27‐1.0 lux | Lluna plena en una nit clara
3.4 lux | límit fosc del crepuscle sota un cel clar
50 lux | llums de la sala d'estar familiar
80 lux | Passadissos, lavabos
100 lux | Dia molt fosc ennuvolat
320‐500 lux | Llum en una oficina
400 lux | Sortida o posta de sol en dies clars
1000 lux | Dia ennuvolat
10000‐25000 lux | Plena llum del dia (sol no directa)
32000‐100000 lux | Sol directe
Article de la Viquipèdia de Lux / CC BY

Ara que entenem una mica millor el funcionament del TEMT6000, es pot utilitzar en alguna cosa més interessant, com el control de llum exterior de la casa per que s'encengui i s'apagui automàticament, segons la llum ambient.

El circuit següent mostrar el connexionat del sensor de llum ambiental TEMT6000 en el sistema central.

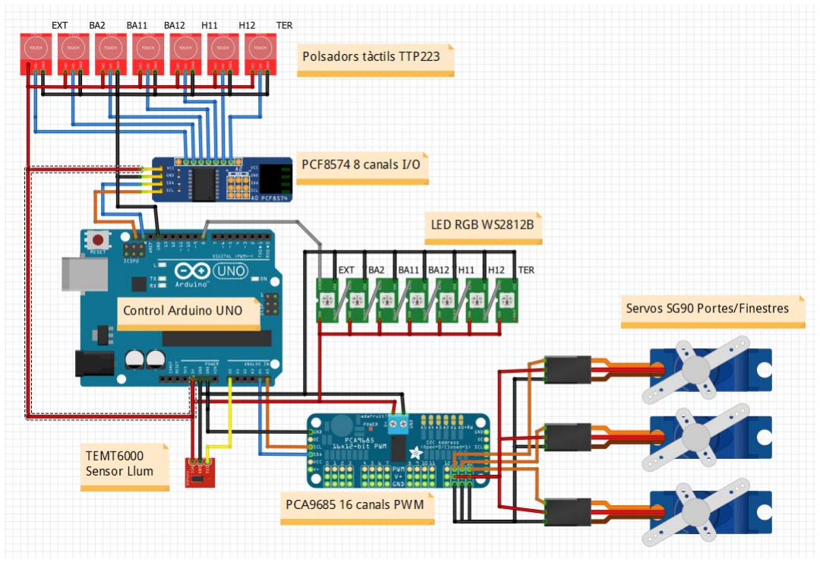
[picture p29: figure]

### Control d’accés

Per accedir a la casa es faran servir diverses tecnologies RFID (identificació per radiofreqüència), empremta dactilar, BT, WiFi...

Control d’accés amb lector RFID

La identificació per radiofreqüència s’utilitza en sistemes de seguretat i de pagament, entre d’altres, per el que en serveix per utilitzar‐lo en aquesta aplicació. Hi han diversos sistemes depenen de la freqüència que s’utilitzi, aquí es fa servir la d’alta freqüència a 13,5MHz, treballa en el entorn de pocs centímetres, gairebé tocant.

En la següent pàgina web es pot trobar una informació molt completa: https://programarfacil.com/blog/arduino‐blog/lector‐rfid‐rc522‐con‐arduino/

Per una banda tenim un mòdul RFID de lectura/escriptura amb el xip RC522 que estarà a l’entrada de la casa i per altre banda hi ha una targeta, clauer, etiqueta adhesiva i d’altres formats (anomenats TAG) que inclouen un xip de RF amb la seva antena, un número d’identificació únic (gravat en el propi silici) i una memòria de 1kB dividida amb 16 sectors, i cada sector en 4 blocs, i cada bloc en 2 bytes de dades, aquests sectors es poden protegir i això permet, que mitjançant un protocol determinat (ISO), obtenir un nivell de seguretat molt alt. No necessita cap bateria per alimentar (per això es diu “passiu”), ja que s’alimenta de l’energia de la pròpia radio freqüència emesa per el mòdul lector RC522.

Aquí es mostra un circuit d’un TAG on es pot veure la complexitat integrada en el xip. Aquest TAG també s’anomena “Transponder”.

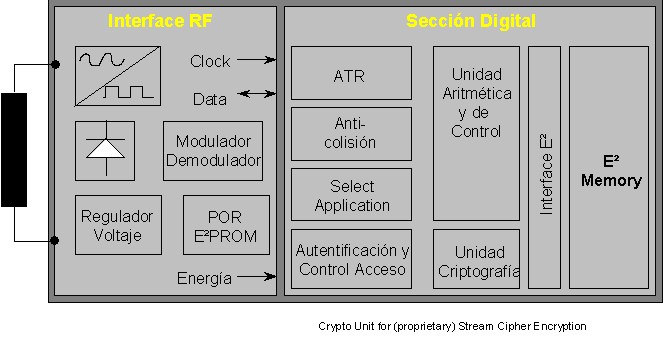
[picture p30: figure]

El mòdul RC522 emet una freqüència (13,5MHz) que fa que aquesta energia alimenti el TAG i pugui intercanviar dades.

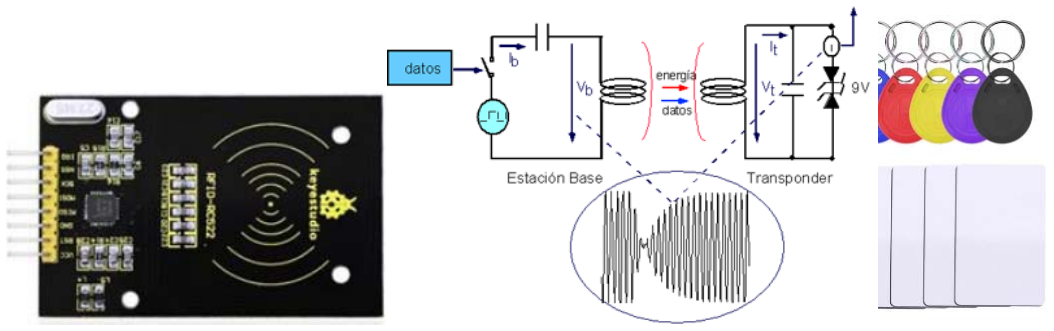
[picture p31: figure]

L’abast de la comunicació entre el lector i el TAG depèn de les dimensions de les antenes tan del lector com del TAG i també del entorn, per això quan es parla del abast, s’ha de parlar de gairebé tocant.

La comunicació entre el mòdul i el sistema de control es pot fer via UART, SPI, i I2C. Típicament es fa servir la comunicació SPI per la alta velocitat de transmissió de dades, però com es pot veure fa servir 5 fils (a part de alimentació).

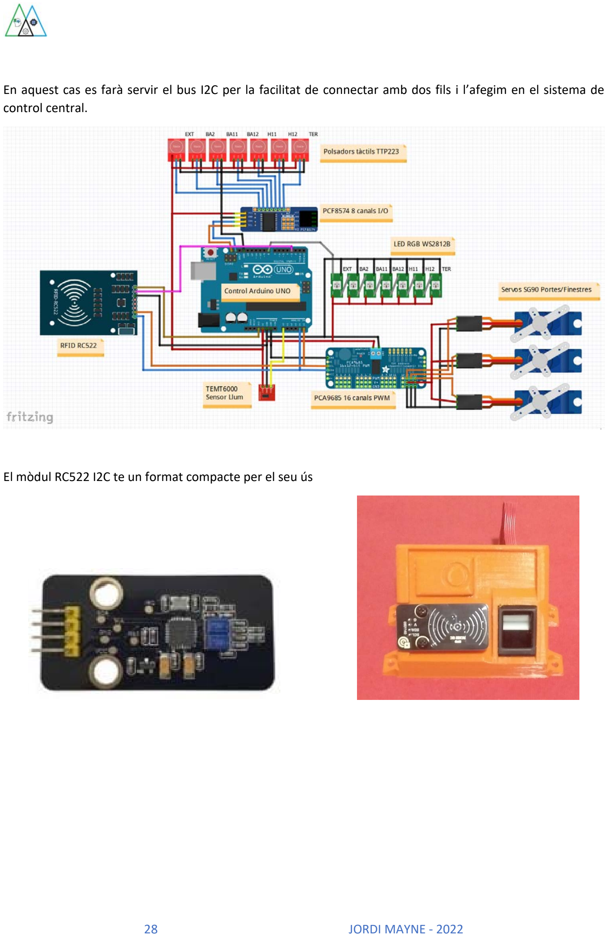
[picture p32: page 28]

En aquest cas es farà servir el bus I2C per la facilitat de connectar amb dos fils i l’afegim en el sistema de control central.

El mòdul RC522 I2C te un format compacte per el seu ús

### Control del ascensor

Es fa servir un motor pas a pas 28BYJ‐48 que incorpora reductora i per la seva forma s’acobla be al muntatge, amb una unió es connecta a eix roscat de 4mm per on es desplaça la cabina del ascensor a més d’una guia llisa.

Dos finals de cursa, un a la part més baixa i l’altre a la part superior identificaran la posició, i amb dos polsadors tàctils TTP223 s’accionarà el funcionament. També es col∙loca una llum a LED a la cabina

Seguidament es mostra el connexionat al sistema de control, el motor necessita un driver de motor ULN2003A.

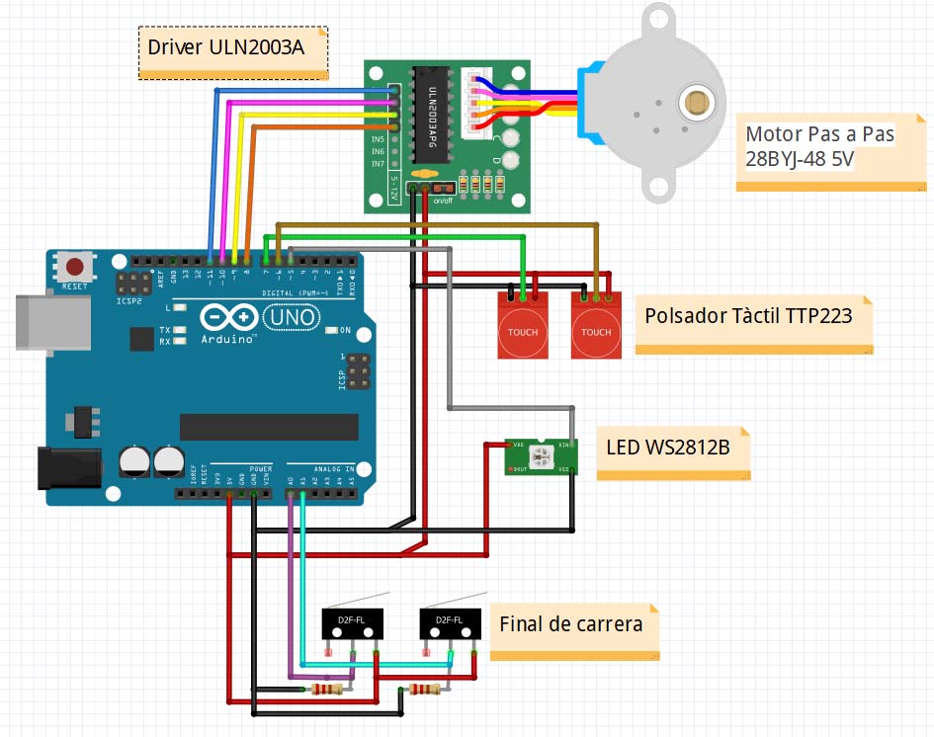
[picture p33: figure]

### Visualitzador Central

Aquesta solució shield de LCD més teclat, permetrà visualitzar l’estat dels llums, portes, finestres, sensors, etc... Aquesta Shield punxada sobre d’una placa ESP32 permetrà a més una comunicació Bluetooh/Wifi i el control sensor més.

### Control d’accés amb lector empremta dactilar (sensor biomètric)

La identificació mitjançant la empremta dactilar es un altre sistema que utilitza alguns punts determinats de l’empremta del dit per identificar la persona. El mòdul FPM10A incorpora un sensor òptic i un processador digital de senyal (DSP) del alta velocitat capaç d’aplicar uns algoritmes per identificar i verificar les empremtes, que junt amb una memòria per emmagatzemar els usuaris (fins a 300). En menys d’un segon pot verificar l’empremta.

Es comunica via sèrie amb el sistema de control

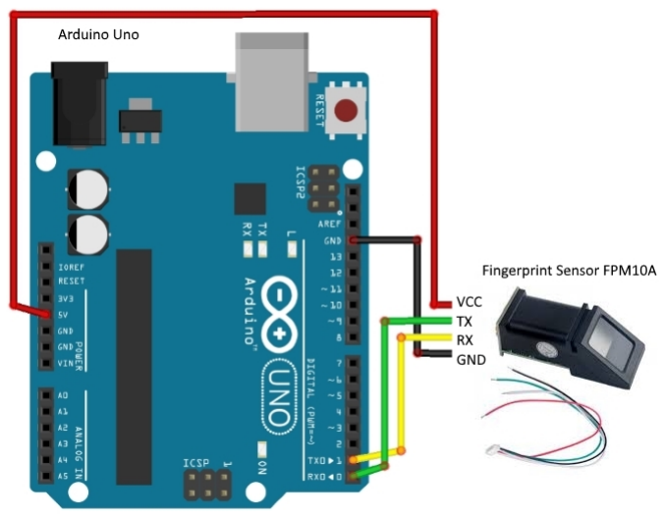
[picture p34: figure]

### Sensor de Temperatura i Humitat

El sensor d’humitat i temperatura molt utilitzat es el DHT11, que te una sortida analògica, que es connectarà a una entrada analògica del Arduino, o ESP32.

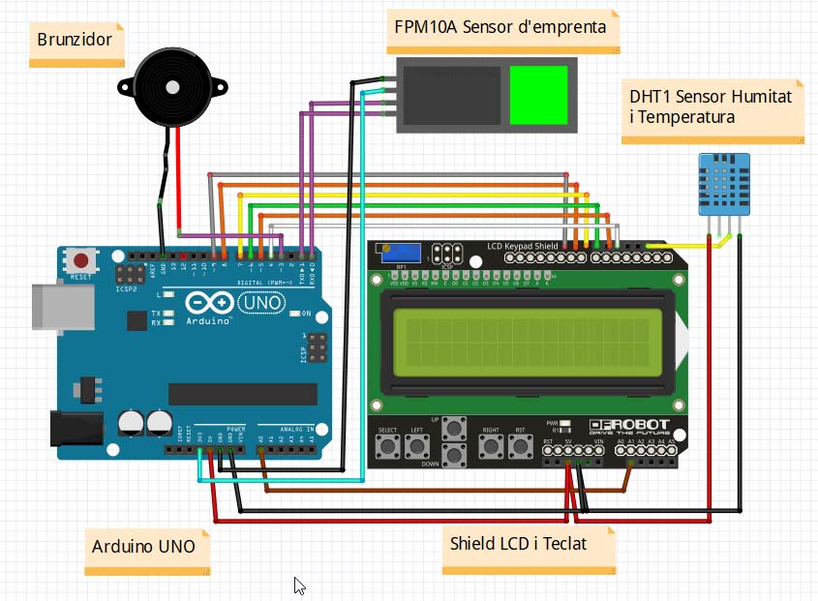
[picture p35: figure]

Es pot veure altre vegada que estem deixant la placa sense entrades/sortides. Es qüestió de buscar una solució, utilitzant un sensor d’humitat i temperatura amb comunicació bus I2C, el SHT31.

### Brunzidor passiu

Es farà servir com a timbre de la casa i altres sons d’alarma o emergència.

### Sensor de Gas

Depenent del tipus de gas que volem detectar, podem posar alguns dels sensors disponibles com el MQ2

### Sensor de Flama

Aquest si que es pot utilitzar en cas d’incendi, encara que espero que no es cremi la maqueta, es pot col∙locar en una zona externa per poder simular un foc amb un encenedor.

Així tindríem en aquests moment el connexionat

### Sensor de pluja

La presencia de vapor d’aigua o pluja pot activar aquest sensor, que te una sortida analògica, que es connectarà a una entrada analògica del Arduino, o ESP32.

## Programació de la casa

Com ja s’ha indicat aquest projecte es obert tant en la construcció i en la programació, sota una llicencia Creative Commons, on es poden aplicar diferents plaques i processadors amb moltes possibilitats. Però com sempre anirem pas a pas.

A més de preparar alguna exemple, aquesta maqueta precisament es per poder practicar programació i per tant qui vulgui “jugar” amb ella el millor es tenir la memòria buida i començar una programació des de cero, des de una part senzilla com encendre uns LED determinats, fer anar els servos per obrir o tancar una porta o finestra, o fer mesures amb els sensors. Però també depenent del nivell de la persona es pot fer un sistema complexa i global.

Se puede usar C para Arduino, Arduino Blocks o cualquier otro medio por bloques

### Programació amb Arduino

La programació amb Arduino es pot fer utilitzant Arduino Blocs, Scratch per Arduino, Snap, ... però també es pot fer amb llenguatge C per Arduino. En qualsevol cas a l’hora de programar sempre s’ha de preparar l’estructura del programa per senzill que sigui.

### Estructura de programació

Per estructurar la programació, cal mirar dels components que tenim i els recursos disponibles. Quan s’ha plantejat fer servir un component s’ha vist que per utilitzar menys pins de entrada/sortida es fan servir altres plaques per concentrar o canalitzar la informació, per exemple, com que hi ha molts polsadors, es concentren aquestes sortides de polsadors a un convertidor a I2C, llavors es pot començar a enumerar cada polsador a una adreça I2C, al mateix amb el concentrador de I2C a servomotor. Per el que cal definir tots els components. Desprès es fa un diagrama de flux per preparar les funcionalitats i finalment el programa.

### Definició de components i funcionalitats

En aquest cas per definir cada component ens referim en el mapa de la casa on es descriu la situació de cada component..

Funcionalitat del TTP223 | Grup | Acció | Component Placa PCF8574 | Adreça I2C
Interruptor | G1_1 | Obre/tanca finestra Bany 1 BR1 W1 | PCF1P0 | 0x20
Interruptor | G1_2 | Encén/apaga llum LED39 i LED40 | PCF1P1 | 0x20
Interruptor | G1_3 | Encén/tanca llums exterior LED3 | PCF1P2 | 0x20
Interruptor | G2_1 | Obre/tanca finestra Bany 2 BR2 W2 | PCF1P3 | 0x20
Interruptor | G2_2 | Encén/apaga llum LED38 i LED41 | PCF1P4 | 0x20
Interruptor | G2_3 | Obre/tanca porta Bany 2 BR2 D2 | PCF1P5 | 0x20
Interruptor | G3_1 | Obre/tanca finestra Bany2 | PCF1P6 | 0x20
Interruptor | G3_2 | | PCF1P7 | 0x21
Interruptor | G3_3 | | | 0x21
Interruptor | G4_1 | | | 0x21
Interruptor | G4_2 | | | 0x21
Interruptor | G4_3 | | | 0x21
Interruptor | Grup 5 | | | 0x21

### Enllaços interesants

https://www.prometec.net/lcd‐keypad‐shield/

https://create.arduino.cc/projecthub/electropeak/using‐1602‐lcd‐keypad‐shield‐w‐arduino‐w‐examples‐ e02d95

https://solectroshop.com/es/content/104‐como‐configurar‐pantalla‐lcd‐16x2‐y‐lcd‐keypad‐shield‐en‐ arduino

https://www.elecrow.com/wiki/index.php?title=LCD_Keypad_Shield

https://www.makerelectronico.com/shield‐lcd‐keypad‐arduino/

https://www.cohesivecomputing.co.uk/hackatronics/arduino‐lcd‐menu‐library/

## Resum de peces impreses

- Parets Casa 26
- Marcs i vidrieres finestres grans 8 + 8
- Marc i vidriera finestra mitjana 1 + 1
- Marcs i vidrieres finestres petites 9 + 9
- Servos finestres + portes 19
- Reixes mur 3
- Portes 10
- Aire condicionat 7
- Parets Garatge 6
- Columnes 2
- Porta i accessoris 6
- Servos 3
- Portes 2
- Ascensor 6 peces
- Murs Pati 7
- Reixes mur 11
- Peu carrer 5
- Teulada frontal 7 + 11
- Teulades posteriors 4 + 4
- Carrer (pendent)

## Altres possibilitats de la maqueta

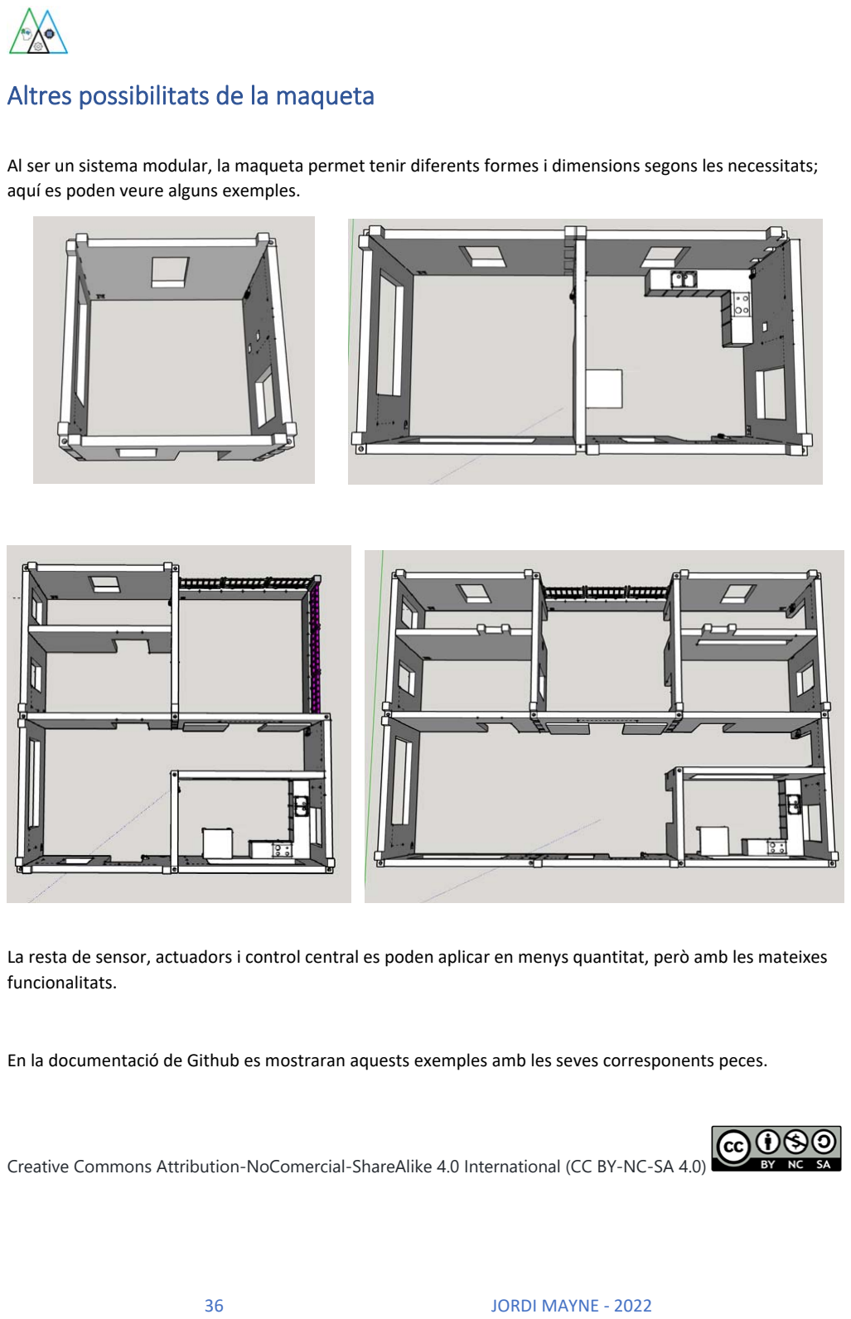
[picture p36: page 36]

Al ser un sistema modular, la maqueta permet tenir diferents formes i dimensions segons les necessitats; aquí es poden veure alguns exemples.

La resta de sensor, actuadors i control central es poden aplicar en menys quantitat, però amb les mateixes funcionalitats.

En la documentació de Github es mostraran aquests exemples amb les seves corresponents peces.

### Creative Commons Attribution-NoComercial-ShareAlike 4.0 International (CC BY-NC-SA 4.0)

## Agraïments

- Més que mai a la Conchita, la meva esposa i companya, per la seva comprensió amb els embolics em que em poso.
- Als components de Mechatronic Study, en Ramon Mayné i en César de la Rosa que han col∙laborat en idees i en la correcció dels texts.
- Als meus fills Isaac i Ferran Mayné, (Web, Github i altres punts)
- A les netes Júlia i Naia que m’han deixat els seus Playmobils per la casa.
- A l’arquitecte Carles Ferran, per els seus consells sobre la casa i la il∙luminació.
- En Josep Ballarà per la fusteria.
- En Ricard Gómez i l’Oriol Oreo del Punt Multimèdia del Ajuntament de Barcelona, per deixar‐me un espai en la Casa del Mig, per poder seguir muntant la maqueta quan a casa ja no hi cabia. A més, en Ricard ha realitzat l’estructura de programació en C per Arduino.
- En Pablo per que posi el codi QR per facilitar l’enllaç en la web de Github.
- En Toni Moreno i InnovaDidactic per la seva implicació en el projecte i la donació de material electrònic per la mateixa.
- A 3D Print BCN on he aprés molt.
- I també a una llarga llista de persones, que no les vull nombrar per no deixar‐me cap, que m’han recolzat en el projecte.

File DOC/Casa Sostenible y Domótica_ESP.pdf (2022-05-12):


1 | JORDI MAYNE ‐ 2022

# Parque medioambiental y casa domótica sostenible

## Objetivo

Construir un parque medioambiental educativo donde estén representados espacios de nuestro entorno donde vivimos, arbolas, huerto, rio... y una casa sostenible aplicando la domótica, gestionando el medio ambiente y midiendo parámetros de la naturaleza.

## Dinámica educativa

- Se pretende que sea Abierto, Didáctico, Evolutivo, Modulable, Flexible y de bajo costo.
- La construcción de la maqueta está preparada para ser impresa en una impresora 3D convencional, pero se puede hacer con madera o cartón pluma y al ser modular permite adaptarla a las necesidades.
- Permite gestionar las luces a LED de colores, Sensores, Actuadores y otros elementos electrónicos para hacer la parte domótica y gestión que se podrá controlar con un Arduino, Microbit o Rasberry ...

Como se podrá ver en toda la descripción, se quiere que se puedan explorar el máximo tipo de elementos y tecnologías.

## Descripción general

### Generación de Energía

La generación de energía es uno de los puntos de estudio y aplicación en la maqueta: Eólica, Solar, Térmica, Geotérmica, Hidráulica

### Sensórica Externa

Medir parámetros de nuestro entorno ayudará a gestionarlo, como la Temperatura y Humedad ambiente, Humedad del suelo, Presión atmosférica, Luz, Color, Rayos ultravioletas, Calidad del aire y agua, Nivelas de agua, Velocidad y dirección del viento, Partículas en el aire.

### Casa Domótica

Control del máximo de elementos usando tecnologías diversas como la Luz, Acceso, Toldo, Ventilación, Calefacción, Motores, Válvulas, Intrusión, Panelas Fotovoltaicos, Térmicos, Acumuladores de energía.
Se detectará Gas, Fuego, Luz, Sonido, Humidad, Temperatura ambiente, Temperatura del agua, Presencia (PIR, IR), Alarma, Intrusión.

### Comunicaciones

Dentro de un entorno sostenible, las comunicaciones son necesarias si se gestionan bien como Bluetooth, Wifi, Ethernet, RFID

## Realización del proyecto

- Descripción de cada parte de la maqueta.
- Selección de materiales y componentes.
- Desarrollo de cada parte.
- Construcción de la maqueta.
- Composición del control electrónico.
- Control global de la maqueta.

### Maqueta

La maqueta se divide en dos partes, una es la Casa propiamente y la otra su entorno que le llamo Parque, debido a las dimensiones de la misma, unos 80x85cm cada parte. Esto empieza a definir la forma modular de este proyecto. Seguidamente se describe cada una de las partes.

## Parque medioambiental

### Estación Meteorológica

- Piezas hechas con una impresora 3D ya diseñadas a Thingiverse, hay muchas posibilidades.
- No podrá tener unas dimensiones proporcionales a la maqueta de la casa por la propia física.
- Estará situada en la parte opuesta a la casa para mejorar su perspectiva.
- Comunicará vía radio (Wifi o Bluetooth) con la central de control de la casa, donde una pantalla mostrará todos los datos.

(Estación meteorológica)

Opción 1: Módulo GY‐39 Intensidad de luz MAX44009 + BMP280 Temperatura, Humedad, Presión

Opción 2: GY‐30 (Intensidad luz) o GY302 o GY‐49 (Intensidad luz) MAX44009,
BMP280 (Presión, Temperatura), DHT11 (Humedad, Temperatura) Módulo Wifi ESP 32

Velocidad del viento (contactos reed + imán)
Dirección del viento (reed + imanes) Pluviómetro (reed + imán)

### Huerto y Arboles

Un recipiente lleno de tierra hará de huerto, se medirá la humedad de la tierra y junto con la temperatura y la luz se programará el riego.

(Huerto)

### Generación de energía

Panel Fotovoltaico con seguidor solar para generar electricidad
- https://www.thingiverse.com/thing:4056888
- Célula Solar 5V
- Motors servo MG90.
- Célula LDR | (Panel Solar)

Panel Térmico para calentar agua
- Tubo en serpentín formando un panel solar.
- El agua caliente entra en un depósito acumulador.
- Sensor de Temperatura
(Panel Térmico)

Aprovechamiento Geotérmico
- Tubo en serpentín bajo tierra con una Peltier para simular el comportamiento subterráneo.
- Tubo en serpentín en el suelo de la casa
- Sensor de Temperatura | (Aprovechamiento Geotérmico)

Generador Eólico para generar energía eléctrica
- https://www.thingiverse.com/thing:1767153
- Dinamo: motor dc 15.2 x 19.8 mm, rotor 2 mm.

(Generador Eólico)

Generador Hidráulico para generar energía eléctrica
- Un depósito superior configura un canal de agua hasta un pequeño salto donde hará mover las palas del generador, el agua sigue hasta un pequeño estanque, que deriva a un aprovecha el agua para regar el huerto y árboles.
- https://www.thingiverse.com/thing:802284
- Salto de agua con dinamo: motor dc 15.2 x 19.8 mm, rotor 2 mm.
(Turbina de agua)

Casa Sostenible y Domótica • Las nuevas casas han de ser sostenibles, aprovechando todas las energías renovables que estén a

nuestro alcance (eólica, térmica, solar, hidráulica, geotérmica).
- Recogida del agua de lluvia para reaprovecharla.
- Aprovechando la luz solar y el viento.
- Aislándola con un tejado verde.
- Control de residuos.
- Control domótico.

### Diseño de la maqueta de la casa

Para hacer la maqueta busqué ideas y maquetas realizadas con impresión 3D. Solo encontré esta https://www.thingiverse.com/thing:2364628 que me pareció una bona forma de ensamblar las paredes, así como sus dimensiones (escala 1:24) para poder incluir y manipular los actuadores, aún que la he transformado y adaptado a las necesidades buscadas.

(1)

La maqueta se ha diseñado para cubrir todas las necesidades para aplicar tecnología. Primero dibujando toda la casa, con unas dimensiones importantes 850x800mm y después hecha a trozos para poderla imprimir en una impresora 3D convencional de 200x200mm y de esta manera se puede tratar de forma modular y realizar con los mismos módulos otros tipos de configuración de la casa. También incorporan las fijaciones de los actuadores en las puertas, ventanas, y alojamientos de las luces. Los tejados se pueden sacar muy fácilmente para mirar y acceder al interior de la casa.

(2)

### Identificación y unión de las piezas de la maqueta

- Para hacer la maqueta se ha buscado un sistema de identificación de cada pieza, marcando con una letra cada pared o muro para un construcción guiada y más fácil.


- La unión entre las piezas se ha diseñado para que no se tenga que usar ninguna cola. Esta unión se hace con encajes y un pasador que las fija.

## Descripción del exterior de la Casa

- Casa de tipo unifamiliar que sea accesible para manipular los diferentes componentes.
- Puerta para vehículos exterior motorizada para ir al garaje. Acceso vía Bluetooth.
- Puerta de acceso a la finca. Timbre, y acceso con identificación RFID.
- Iluminación autónoma a LED, con detección de presencia y de luz diurna.

### Puerta de entrada de vehículos

Puerta batiente con acceso remoto vía Bluetooth para identificar y abrir.

- Mecanismo cremallera con servo‐motor de 360 grados MG995.
- Identificación vía Bluetooth HM10 o Wifi relé ESP8266
- Luz de señalización de movimiento de Puerta APA106 o WS2812.
- Verde detección ID Bluetooth
- Ámbar movimiento de Puerta
- Rojo Identificación inválida
- Detección de obstáculos de seguridad con IR TCRT5000 | o HCRS04.

### Puerta de acceso a la finca

Como cualquier casa, un pulsador servirá para activar un timbre, también un lector RFID que permitirá abrir la puerta con una tarjeta RFID válida.

- Timbre de llamada con pulsador
- Lector RFID RC522 con bus I2C
- Puerta motorizada con Servomotor SG90

### Iluminación exterior de la casa

Luces LED de color tipo WS2812 y un sensor de proximidad PIR HC‐SR501 con sensor de luz diurna para iluminar la puerta de entrada o las permanentes para la noche desde el control central.

### Depósito de agua de lluvia

El agua de lluvia se recoge desde los tejados de la casa, se almacenan en un depósito interno para usar para lavabos, ducha, wc, lavadora.

- Sistema de control de bombeo.
- Control de nivel de agua.

## Descripción del interior de la Casa

- Control de acceso puertas exteriores
- Sistema de alarma
- Control de luz LED individualizada con intensidad y color
- Guía luz solar con apoyo con luz de LED
- Control ventanas batientes motorizadas
- Control de puertas motorizadas
- Control Ventilación, Calefacción, Refrigeración
- Ascensor
- Toldos motorizados

### Puerta de acceso a la casa

- Lector RFID RC522 | Lector huella dactilar
- Servo SG90

### Luz interior de la Casa

El control de la luz se hace tanto manual como automáticamente, mediante sensores.

- LED + Detector IR para pasillos HC‐SR501
- LED + Interruptor/pulsador sensitivo TTP223
- LED + Sensor de voz para la despensa
- Led + Sensor de luz ambiental TEMT6000 | o LDR

### Guía luz solar

Cilindro de metacrilato guía la luz solar hacia el interior de la casa, al atardecer y por la noche una luz LED hace la función solar.

(6)

(5)

### Control de toldo

- Toldo o persiana motorizado
- Motor paso a paso K976 (7)

### Aire acondicionado

Un sistema central de aire acondicionado formado por una célula Peltier genera calor o frío por inversión de polaridad, y un ventilador mueve el aire para toda la casa.

- Temperatura LM35 | o DS18B20
- Humidad y Temperatura | DTH11 o SHT31
- Ventilador + Peltier (Enfría/Calienta)

### Sistema de Alarma

Un sistema integrado de alarma contra intrusión, fuego, gas

- Sensor de vibración/inclinación SW‐520D
- Contactos con imanes en ventanas
- Sensor de gas MQ‐2
- Sensor de llama
- Zumbador

### Pantallas de control

- Pantallas Oled o LCD, donde se distribuirá la información para trabajar por áreas. También se podrá tener acceso desde un teléfono inteligente, “Tablet”.
- Monitorización de datos de la estación meteorológica.
- Monitorización del control de acceso a la casa, garaje, sistema de seguridad.
- Monitorización de la refrigeración, ventilación, calefacción
- Monitorización del ascensor.

### Sistema central de control

El control también se ha pensado abierto, si no ya no sería didáctico. Todos los actuadores y sensores se pueden adaptar a las plataformas más utilizadas como Arduino, ESP32, Microbit o Raspberry.

El software de programación de estas plataformas permite utilizar diferentes lenguajes de programación, Scratch para Arduino, C++ para Arduino, ArduinoBlocks, MakeCode, Python entre otros.

- Arduino, ESP32: Scratch, Arduino Blocks, C++
- Microbit: MakeCode, Python, C++
- Raspberry: Python, Java, Linux

Alimentación y baterías.

La maqueta al igual que muchas casas actuales donde se genera energía para el autoconsumo, necesitan también energía eléctrica adicional. La maqueta tendrá generadores de energía que cargaran unas pequeñas baterías, pero también tendrá una fuente de energía a la red.

Planteamiento de la casa Como que no soy arquitecto seguro que no he realizado una casa "bonita“, ni arquitectónicamente correcta,

pero tengo la suerte de tener amistades arquitectos que me han ayudado a hacer algunas correcciones.

Lo que pretendo es aplicar diferentes tecnologías para hacer una casa sostenible, aprovechando las energías renovables y hacer concienciación de nuestro entorno.

El garaje bajo tierra se justifica para poder tener un ascensor con su control. Y además poder tener debajo de la casa el cableado de control totalmente manipulable, el depósito de recogida de agua de lluvia y el depósito de tratamiento de aguas azules.

El acceso a los dispositivos tanto de la casa como del resto es accesible, para poder ver o cambiar los sensores, actuadores o sistema de control de cualquier rincón.

## Planteamiento del control

- El control se podrá hacer a través de tareas individualizadas o agrupadas junto con la pantalla o pantallas para mostrar sus funcionamientos o/y con un control central para recoger el funcionamiento global.
- Muchas tareas se harán simuladas intentando reproducir al máximo su funcionamiento real.
- Los sensores básicos utilizados se podrán cambiar por otros más caros o sofisticados, está previsto que su acceso y cableado lo permita.
- Algunos actuadores/sensores serán diferentes para probar todas las tecnologías.

Este apartado se mostrará al final de la construcción de la maqueta

### Maqueta interior casa

(8)

### Maqueta Casa, Garaje y Patio

El patio está encima del garaje y deja un espacio para albergar el ascensor.


### Maqueta Garaje y Ascensor

Detalle del mecanismo de la puerta de garaje

(13)

### Ascensor

El ascensor tiene dos plantas. Permite acceder a la casa desde el garaje.

- Un motor paso a paso en la parte superior proporciona un desplazamiento preciso y lento. 28BYJ‐48 DC 5V
- La cabina tiene dos guías, una lisa y otra con rosca M4

(14)

### Ventanas batientes y puertas motorizadas

- Las ventanas son batientes con movimiento a través de un servo‐motor.
- Las puertas también están motorizadas a través de un servo‐motor.
- Totes las puertas y ventanas tienen los anclajes en la pared para poner un servo‐motor.

### Aire acondicionado


- Una máquina en el salón distribuye el aire frío y caliente.
- Un ventilador de 40x40x10 impulsa aire que pasa para una célula Peltier. Cambiando la polarización de la Peltier produce frío o calor.
- Los tubos conducen hacia todas las estancias.

(16)

### Tejados

Hay tres tejados, el frontal y dos posteriores, con una base con los canales de agua de lluvia, y por la parte inferior incorpora los espacios donde irán instaladas las luces externas a LED.

- Tejado Frontal
El tejado frontal será semitransparente y con una
cubierta interior textil motorizada para
aislamiento térmico y paso de luz.
Permite observar el interior del salón/comedor y cocina.

(17)

- Tejado Verde
El tejado verde de los dos laterales permite drenar el agua y formar un aislamiento térmico, así como un entorno visual mejor.

Por debajo hay los alojamientos de las luces de las habitaciones y las luces externas, y el canal de las conexiones, para que se pueda sacar el tejado de la maqueta para acceder al interior.
El agujero redondo permite instalar un guía luz.

(18)

El tejado estará cubierto de verde, con plantes y diferentes capas de materiales que permiten un aislamiento de la casa y drenar el agua de lluvia.

(19)

### Tejados en la maqueta


### Aceras de la casa

- Las aceras simulan un empedrado.
- Todas las piezas tienen unos agujeros para fijar las piezas a la base de la madera de la casa.

(20)

### Sujeción de la maqueta

Todas las paredes tienen un agujero en la base para anclarse a la base de madera de la casa.

(21)

En la base de madera contrachapado de 5mm, primero se acota tota la maqueta y se mecaniza.

(22)


Antes de fijarla se aprovecha para enmoquetar el suelo del interior y el césped del exterior.

Seguidamente ya se puede fijar la maqueta

Ara ya se puede continuar trabajando con el resto de la casa, poniendo los marcos de las puertas y ventanas


La base de madera de la casa se puede utilizar otro tablero de 10mm contrachapado, separado por columnas de 120mm de altura, que es la medida exacta del garaje. Este espacio servirá para colocar la alimentación, baterías, electrónica, displays, lector RFID, lector dactilar, etc ...

El tejado semitransparente se puede hacer con una hoja de plástico a partir 1mm de grueso para que tenga un poco de consistencia. Se ha de cortar para el tejado frontal a 176x132mm y para el tejado del salón/comedor/cocina con dos de 176x290mm.


### Montaje electrónico

Para empezar con el sistema electrónico se puede preparar el conexionado de las luces de LED multicolor WS2812B en la parte posterior de los tejados. Usando tres hilos (positivo 5V,
negativo (gnd) y datos) con tres colore bien diferenciados para no cometer ningún error, se
pueden trenzar los hilos en forma de espiral y sujetarlos con tubo termo‐retráctil.

Las soldaduras han de estar bien hechas y que no puedan cruzar conexiones, hace falta al terminar una revisión visual, antes de colocarlo en los encajes del tejado y hacer una prueba de funcionamiento.

Una vez que se tiene el cableado terminado, se coloca en la guía correspondiente y se fija con un poco de cola termo‐fusible.

## Planteamiento del control

Tal como se ha expuesto al principio de este documento, el control se podrá hacer a través de tareas individualizadas o agrupadas para facilitar una programación por partes y para facilitar el uso de un hardware sencillo. De esta manera se pueden establecer funcionalidades básicas hasta las más complejas, así como funcionalidades futuras.

### Tareas individualizadas

En este apartado se mostraran las tareas que se pueden realizar para trabajarlas individualmente así como su hardware asociado.

### Control de las luces de la casa

Las luces de la casa son de LED del tipo RGB WS2812, que permiten obtener el color que se quiera (por programa), así como la intensidad de luz deseada. Esto permite hacer escenarios diferentes con la iluminación exterior. Y en el interior hacer una iluminación más cálida para las habitaciones o más fría para la cocina. Estas luces pueden ser automáticas como el caso de las luces exteriores, con un sensor de luz ambiente, o a través de pulsadores táctiles en cada habitación. También se podrá activar alguna luz con un sensor de presencia, como puede ser un pasillo del ascensor y garaje. Por tanto, si se hace flexible la instalación de elementos de control dará más margen de usar más medios de control y de futuras ideas.

Primero de todo hace falta enumerar cada punto de luz de la casa.


Los círculos de color verde son las luces del exterior de la casa, que posiblemente se harán encender todas a la vez y con el mismo color, pero se podrán programar escenas con diferentes colores e intensidades de luz. En color verde también hay los puntos de luces
externas, pero, del patio interior, este agrupamiento se puede hacer separadamente de las
otras con un color fijo. Los círculos de color amarillo son parte de la iluminación interior,
salón‐comedor, cocina, dormitorios baños y pasillos. Estas luces tienen los puntos de encendido señalizados como G1, grupos de 3 pulsadores que pueden actuar como pulsador o interruptor, numerados como G1_1, G1_2, G1‐3. También se usarán estos pulsadores táctiles para abrir y cerrar ventanas como W1 o puertas como D1. Finalmente, también se enumeran los espacios como BR1, BR2, R1...

Todos estos puntos de luz a LED van conectados en serie en el orden indicado de numeración, y se utilizan 3 hilos (positivo, negativo y datos), estos hilos irán conectados a la placa de control que se use (ya sea Arduino, ESP32, Microbit, Raspberry...) y así solo utiliza un pin de salida.

### Pulsadores/Interruptores

En la maqueta hay puntos de pulsadores para activar luces, servos, estos pulsadores son táctiles utilizando el circuito TTP223, un circuito que permite diverses maneras de trabajar, como un pulsador o como un interruptor. Aún que tiene otras funcionalidades.

Las particularidades de este circuito que se muestra en el esquemático, es que se puede alimentar entre 2,5 y 5Vdc, directamente entrega un estado de salida dependiendo de las conexiones de los pins A y B, un LED indica el estado de salida.


Conexionado | Acción
Sin puente B | Pulsador
Con puente B | Interruptor
Con puente A | Nivel alto por defecto

El conexionado del pulsador táctil tendrá una conexión del puente B, para tener funcionalidad Pulsador o Interruptor según se quiere programar. Estará disponible en la parte inferior de la casa con un conector puente.

Así quedaría el conexionado con la placa Arduino, pero ya se ve que utiliza muchos pins de entrada.


### Expansión de entradas y salidas en un Arduino

Como que es necesitan muchas entradas de pulsadores para las luces y servos, hace plantear utilizar varias placas Arduino, cosa que no es la solución más adecuada. Es mejor colocar un expansor de entradas, que se puede hacer con un módulo multiplexor analógico o con un módulo expansor I2C.

74HC4067 multiplexor de 16 canales, se alimenta entre 2,5V y 6V, permite hasta
16 canales (C0 a C15) de entrada o salida y se necesitan 3 señales de control (S1
a S3), dos pins de alimentación y uno de Enable.

Pero, no es la mejor solución en cuanto a consumo y número de hilos hacia el microcontrolador.

Una solución más avanzada es utilizar un circuito que se comunica con el microcontrolador con 2 hilos, vía I2C.

PCF8574 es un expansor de 8 canales digitales de entrada/salida con comunicación I2C hacia el microcontrolador, por defecto al alimentar el circuito son entrades digitales (P0 a P7), funciona entre 2,5 y 6V, incorpora 3 pins (A0 a A2) para configurar la dirección I2C (desde 0x20 a 0x27), tiene dos pins de comunicación típicas de I2C, SDA (datos), SCL (reloj) y un pin INT (interrupción) que se pone a nivel 0 cuando hay un cambio de flanco en algunas de las entradas/salidas del chip, esto permite no tener que rastrear constantemente los pins de entrada hacia el microcontrolador.


Se encuentran con dos formatos de placa, la de color azul permite expandir a más placas PCF8574 para tener aún más canales y la roja no.

La dirección I2C se selecciona con los puentes/interruptores de la placa.

Librería Arduino para el PCF8574 https://www.arduino.cc/rehacerence/en/libraries/pcf8574‐library/

Para conectar diversos PCF8574 en la misma comunicación I2C es de la siguiente manera.

En caso de querer ampliar el número de canales I2C se puede usar el TCA9548 a 8 canales I2C.


Se puede observar que a través de la cubierta de plástico se puede ver la luz roja de actuación del táctil.

### Control de 16 servomotores en un Arduino

Como que se necesitan muchas salidas para todos los servomotores de control de puertas y ventanas; Arduino solo dispone de 6 salidas PWM, por lo que hace utilizar varies plaques, Pero, no es la solución más adecuada. Es mejor utilizar una placa PCA9685 conectada vía I2C con el microcontrolador.

A más los servomotores tienen un consumo elevado, sobre los 200mA multiplicado por 16 son 3,2A

PCA9685 soporta hasta 16 servomotores controlados vía I2C, dispone
de los pins para conectar adecuadamente los servomotores, las
direcciones I2C van desde 0x40 hasta a 0x7F soldando los puentes
(A0...A5), entrega 16 salidas PWM de 12 bits, se alimenta a 5V, y las líneas SDA y SCL de I2C son compatibles 3V3 o 5V.


Servomotores SG90

Un servomotor, denominado también “servo”, es un motor DC con la capacidad de poner su eje en una posición o en un ángulo determinado, internamente tiene una caja de engranajes reductora que hace aumentar el par motor y reduce la velocidad, un potenciómetro está encargado de sensar la posición del eje y junto con una electrónica forman un control en lazo cerrado.

Hay diferentes tipos de servomotores, el más utilizado es el SG90 que es suficiente para la mayoría de aplicaciones. Funciona entre 3 y 7.2V, tiene un par motor entre 1 y 1.6 kg/cm. Otros tienen par motor más grandes llegando hasta 15 kg/cm.

Base para programar los servomotores

https://www.luisllamas.es/controlar‐16‐servos‐o‐16‐salidas‐pwm‐en‐arduino‐con‐pca9685/

Información para más conocimiento sobre los servomotores:

https://dronprofesional.com/blog/tutorial‐teorico‐practico‐con‐servos‐y‐arduino/

Esquemático de control de luces y servos


Montaje del servomotor en un suporte y la fijación a la pared de una ventana y de una puerta.


### Sensor de luz ambiente

De sensores de luz hay diversas posibilidades: el TEMT6000 que solo detecta la presencia amalgamada de luz con longitudes de onda en el rango de 390 a 700 nm. Se encuentra con formatos muy pequeños, como el Lilypad o un formato rectangular para poderlo fijar.

Lilypad | Rectangular

El TSL2561 es un sensor de luminosidad que puede detectar tanto la luz visible como la luz infrarroja. El ISL29125 es un sensor de luz RGB que puede detectar luz específicamente roja, verde, azul o cualquier combinación de estas. El ML8511 es un sensor de luz UV funciona de manera similar al TEMT6000, Pero responde a la luz ultravioleta en lugar de la luz visible. El LDR es una alternativa de tamaño muy pequeño, pero es una foto‐resistencia (una resistencia que cambia en función de la presencia de la luz) en lugar de un fototransistor.

Por eso, el sensor de luz ambiental TEMT6000 es el escogido. Es un sensor analógico, compatible con microcontroladores que admiten la entrada de datos analógicos. Si la luz es muy baja, el pin SIG (salida) tendrá un valor muy bajo, a medida que aumenta la luz, el pin SIG también aumentará de valor. A más, es sensible al espectro visible y se usa en muchos aparatos como smartphones, “tablets”, cameras y está adaptado a la respuesta del ojo humano con respecto a la luz. Tiene un ángulo de 60 grados y se alimenta a 5V.

Como funciona la detección de la luz

Como se ha descrito anteriormente, el TEMT6000 mide la iluminación. Si no se está familiarizado con la iluminación, es una medida de la cantidad total de luz visible emitida para una fuente (denominada flujo luminoso medida en lúmenes (lm) dividida para un área en metros cuadrados (1 lx = 1 lm/m²).

Juntamente con estas, hay otras propiedades de la luz que lamentablemente, se llaman con la misma raíz latina para la luz, de manera que puede ser difícil mantenerlas en orden. Aquí, se muestra un diagrama para aclarar diferencias:

¿Por qué el TEMT6000 mide la iluminación? En la mayoría de ensayos, medir la intensidad de la luz sin tener en cuenta la distancia es muy difícil y desconcertó a los primeros astrónomos durante mucho tiempo. En resumen, hay la magnitud aparente (como de brillante parece una fuente de luz) y la magnitud absoluta (como de brillante es realmente la fuente de luz). Dos fuentes de magnitudes absolutas diferentes pueden tener la misma magnitud aparente dependiendo de su distancia del observador.

Por ejemplo, si se tiene una fuente de luz brillante lejos y una fuente de luz muy cerca, puede parecer que tienen el mismo brillo porqué la luz de la fuente más brillante se tendrá que disipar en un volumen de espacio más grande. Es por esto que el sensor leerá un valor más pequeño si se aleja la misma fuente de luz, aumentando esencialmente la cantidad de espacio que la misma cantidad de luz ha de llenar entre la fuente y el sensor (es decir, reduciendo la iluminación, a medida que se está dividiendo para una superficie más grande de la esfera de luz generada por la fuente de luz).

Aquí se muestra una gráfica, sacada de la hoja de datos del TEMT600, entre la corriente (en µA) y la iluminación inmediata percibida por el sensor:


El TEMT6000 solo reconoce la luz con longitudes de onda en el rango de 390‐700nm, que cubre aproximadamente todo el espectro de la luz visible. En otras palabras, no captará la luz infrarroja, ultravioleta o cualquier otra luz que no se pueda ver directamente.

Aquí se muestra una tabla de la iluminación típica de fuente comunes de luz visible:

Iluminación | Superficies iluminadas por
0.0001 lux | Cielo nocturno nublado y sin luna
0.002 lux | Cielo nocturno claro sin luna con resplandor del cielo
0.27‐1.0 lux | Luna llena en una noche clara
3.4 lux | Límite oscuro del crepúsculo bajo un cielo despejado
50 lux | luces de la sala de estar familiar
80 lux | Pasillos, lavabos
100 lux | Dia nublado muy oscuro
320‐500 lux | Luz en una oficina
400 lux | Salida o puesta de sol en días claros
1000 lux | Dia nublado
10000‐25000 lux | Plena luz del día (sol no directo)
32000‐100000 lux | Sol directo
Articule de la Wiquipèdia de Lux / CC BY

Ahora que se puede entender un poco mejor el funcionamiento del TEMT6000, se puede utilizar en alguna cosa interesante, como el control de luz exterior de la casa para que se enciendan y se apaguen automáticamente, según la luz ambiente.

El circuito siguiente muestra el conexionado del sensor de luz ambiental TEMT6000 en el sistema central.


### Control de acceso

Para acceder a la casa es usaran diversas tecnologías, como RFID (identificación por radiofrecuencia), huella dactilar, BT, WiFi...

Control de acceso con lector RFID

La identificación por radiofrecuencia se utiliza en sistemas de seguridad y de pago, entre otras, por lo que va a servir en esta aplicación. Hi han diversos sistemas dependiendo de la frecuencia que se utilice, aquí se usará la alta frecuencia a 13,5MHz, trabaja en el entorno de un centímetro, casi tocando.

En la siguiente página web se puede encontrar una información muy completa: https://programarfacil.com/blog/arduino‐blog/lector‐rfid‐rc522‐con‐arduino/

Por un lado tenemos un módulo RFID de lectura/escritura con el circuito RC522 que estará a la entrada de la casa y por otro lado una tarjeta, llavero, etiqueta adhesiva o en otros formatos (llamados TAG) que incluyen un chip de RF con su antena, un número de identificación único (grabado en el propi silicio) y una memoria de 1kB dividida en 16 sectores, y cada sector en 4 bloques, y cada bloque en 2 bytes de datos, estos sectores se pueden proteger y esto permite, que mediante un protocolo determinado (ISO), obtener un nivel de seguridad muy alto. No necesita ninguna batería para alimentar (por esta razón se llama que es un elemento “pasivo”), ya que se alimenta de la energía de la propia radio frecuencia emitida por el módulo lector RC522.

Aquí se muestra un circuito de un TAG donde se puede ver la complejidad integrada, este sistema también se denomina “Transponder”.


El módulo RC522 emite una frecuencia (13,5MHz) que hace que su energía alimente el TAG y pueda intercambiar datos.

La distancia de la comunicación entre el lector y el TAG depende de las dimensiones de la antena tanto del lector como del TAG y también de su entorno, por eso cuando se habla de alcance, se ha de hablar de casi tocando.

La comunicación entre el módulo y el sistema de control se puede hacer vía UART, SPI, o I2C. Típicamente se usa la comunicación SPI por la alta velocidad de transmisión de datos, pero como se puede ver usa 5 hilos (aparte de la alimentación).


En este caso se usará el bus I2C por la facilidad de conectar con dos hilos y lo añadimos en el sistema de control central.

El módulo RC522 I2C tiene un formato compacto para su uso.

### Control del ascensor

Es usa un motor paso a paso 28BYJ‐48 que incorpora reductora y por su forma física se acopla bien al montaje, con una unió es conecta a el eje roscado de 4mm que es por donde se desplaza la cabina del ascensor a más de por otra guía lisa.

Dos finales de carrera, uno en la parte más baja y otro en la parte superior identificaran la posición, y con dos pulsadores táctiles TTP223 se accionará el funcionamiento. También se coloca una luz a LED a color en la cabina.

Seguidamente se muestra el conexionado al sistema de control, el motor necesita un driver de motor ULN2003A.


### Visualizador Central

Esta solución shield de LCD más teclado, permitirá visualizar el estado de las luces, puertas, ventanas, sensores, etc... Esta Shield conectada sobre una placa ESP32 permitirá además una comunicación Bluetooh/Wifi y el control del sensor de huella dactilar.

### Control de acceso con lector de huella dactilar (sensor biométrico)

La identificación mediante la huella dactilar es un otro sistema que utiliza para identificar las personas. El módulo FPM10A incorpora un sensor óptico y un procesador digital de señal (DSP) de alta velocidad capaz de aplicar unos algoritmos para identificar y verificar las huellas, que junto con una memoria para almacenar a los usuarios (hasta a 300), en menos de un segundo se puede verificar una huella.

Es comunica vía serie con el sistema de control


### Sensor de Temperatura y Humedad

El sensor de humedad y Temperatura DHT11 es muy utilizado, que tiene una salida analógica, que se conecta a una entrada analógica del Arduino, o ESP32.

Se puede ver otra vez que estamos dejando la placa sin entradas/salidas. Es cuestión de buscar una solución, utilizando un sensor de humedad y temperatura con salida bus I2C, el SHT31.

### Zumbador pasivo

Se usará como a timbre de la casa y otros sonidos programables de alarma o emergencia.

### Sensor de Gas

Dependiendo del tipo de gas que queremos detectar, se pueden diversos sensores disponibles, como el MQ2

### Sensor de Llama

Este sí que se puede utilizar en caso de incendio, aún que sea para que no se queme la maqueta !!!!!, se puede colocar en una zona externa para poder simular un fuego con un pequeño mechero.


Así tendríamos en este momento el conexionado

### Sensor de lluvia

La presencia de vapor de agua o lluvia puede activar este sensor, que tiene una salida analógica, que se conectará a una entrada analógica del Arduino, o del ESP32.

## Programación de la casa

Como ya se ha indicado, este proyecto es abierto tanto en la construcción y en la programación, bajo una licencia Creative Commons, donde se puede aplicar diferentes placas y procesadores con muchas posibilidades. Vamos a ir como siempre paso a paso.

Además de preparar algunos ejemplos, esta maqueta precisamente es para poder practicar programación y por tanto, quien quiera “jugar” con ella lo mejor es dejar la memoria vacía y empezar una programación desde cero, desde una parte sencilla como encender unos LED determinados, hacer mover los servos para abrir o cerrar una puerta o ventana, o hacer medidas con los sensores. Pero también dependiendo del nivel de la persona se puede hacer un sistema complejo y global.

Se puede usar C para Arduino, Arduino Blocks o cualquier otro medio por bloques

### Programación para Arduino

La programación para Arduino se puede hacer utilizando Arduino Blocks, Scratch para Arduino, Snap, ... Pero también se puede hacer con lenguaje C para Arduino. En cualquier caso, a la hora de programar siempre se ha de preparar la estructura del programa por sencillo que sea.

### Estructura de programación

Para estructurar la programación, hace falta ver los componentes que tenemos y los recursos disponibles. Cuando se ha planteado usar un componente se ha visto que para utilizar menos pins de entrada/salida se usan otras placas para concentrar o canalizar la información, por ejemplo, como que hay muchos pulsadores, se concentran estas salidas de pulsadores a un convertidor a I2C, entonces se puede empezar a enumerar cada pulsador a una dirección I2C, lo mismo con el concentrador de I2C a salidas servomotor. Por lo que hace falta definir todos los componentes. Después se puede hacer un diagrama de flujo para preparar las funcionalidades y finalmente el programa.

### Definición de componentes y funcionalidades

En este caso para definir cada componente nos referimos en el mapa de la casa donde se describe la situación de cada componente.

Funcionalidad del TTP223 | Grupo | Acción | Componente Placa PCF8574 | Dirección I2C
Interruptor | G1_1 | Abre/cierra ventana Baño 1 BR1 W1 | PCF1P0 | 0x20
Interruptor | G1_2 | Enciende/apaga luz LED39 i LED40 | PCF1P1 | 0x20
Interruptor | G1_3 | Enciende/apaga luces exteriores LED3 | PCF1P2 | 0x20
Interruptor | G2_1 | Abre/cierra ventana Baño 2 BR2 W2 | PCF1P3 | 0x20
Interruptor | G2_2 | Enciende/apaga luz LED38 i LED41 | PCF1P4 | 0x20
Interruptor | G2_3 | Abre/cierra puerta Baño 2 BR2 D2 | PCF1P5 | 0x20
Interruptor | G3_1 | | PCF1P6 | 0x20
Interruptor | G3_2 | | PCF1P7 | 0x21
Interruptor | G3_3 | | | 0x21
Interruptor | G4_1 | | | 0x21
Interruptor | G4_2 | | | 0x21
Interruptor | G4_3 | | | 0x21
Interruptor | Grup 5 | | | 0x21

### Enlaces interesantes

https://www.prometec.net/lcd‐keypad‐shield/

https://create.arduino.cc/projecthub/electropeak/using‐1602‐lcd‐keypad‐shield‐w‐arduino‐w‐examplas‐ e02d95

https://solectroshop.com/es/content/104‐como‐configurar‐pantalla‐lcd‐16x2‐y‐lcd‐keypad‐shield‐en‐ arduino

https://www.elecrow.com/wiki/index.php?title=LCD_Keypad_Shield

https://www.makerelectronico.com/shield‐lcd‐keypad‐arduino/

https://www.cohesivecomputing.co.uk/hackatronics/arduino‐lcd‐menu‐library/

## Resumen de piezas impresas

- Paredes Casa 26
- Marcos y cristaleras de ventanas grandes 8 + 8
- Marco y cristalera de ventana mediana cocina 1 + 1
- Marcos y cristaleras pequeñas 9 + 9
- Servomotores de ventanas + puertas 19
- Rejas muro 3
- Puertas 10
- Aire acondicionado 7
- Paredes Garaje 6
- Columnas 2
- Puerta y accesorios 6
- Servomotores 3
- Puertas 2
- Ascensor 6 piezas
- Muros Patio 7
- Rejas muro 11
- Pie de calle 5
- Tejado frontal 7 + 11
- Tejados posteriores 4 + 4
- Calle (pendiente)

## Otras posibilidades de la maqueta

Al ser un sistema modular, la maqueta permite tener diferentes formas y dimensiones, según las necesidades; aquí se pueden ver algunos ejemplos.

El resto de sensores, actuadores y control central se puede aplicar de la misma manera, en menor cantidad, pero con las mismas funcionalidades.

En la documentación de Github se mostrarán estos ejemplos con sus correspondientes piezas.

### Creative Commons Attribution-NoComercial-ShareAlike 4.0 International (CC BY-NC-SA 4.0)

## Agradecimientos

- Más que nunca a Conchita, mi esposa y compañera de aventuras, por su comprensión con los enredos que me pongo.
- A los componentes de Mechatronic Study, Ramon Mayné y César de la Rosa que han colaborado en ideas y en la corrección de los textos.
- A mis hijos Isaac i Ferran, (Web, Github y otros puntos)
- A las nietas Júlia y Naia que me han dejado sus Playmobils para la casa.
- Al arquitecto Carles Ferran, por sus consejos sobre la casa y la iluminación.
- A Josep Ballarà por la carpintería.
- A Ricard Gómez y Oriol Oreo del Punt Multimèdia del Ajuntament de Barcelona, por dejarme un espacio en la Casa del Mig, para poder seguir montando la maqueta. Además, Ricard ha realizado la estructura de programación en C para Arduino.
- A Pablo para que ponga el código QR para facilitar el enlace al sitio web de Github
- A Toni Moreno e InnovaDidactic por su implicación en el proyecto y la donación de material electrónico Keyestudio para la misma.
- A 3D Print BCN donde he aprendido mucho en impresión.
- Y también a una larga lista de personas, que no las quiero nombrar para no dejarme a nadie, que me han apoyado en el proyecto.

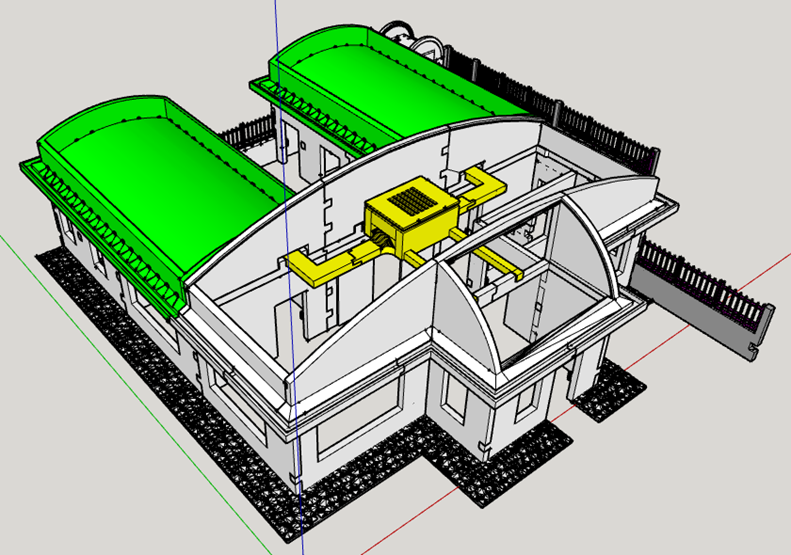
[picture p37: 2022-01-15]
Imatges/Maqueta1.png

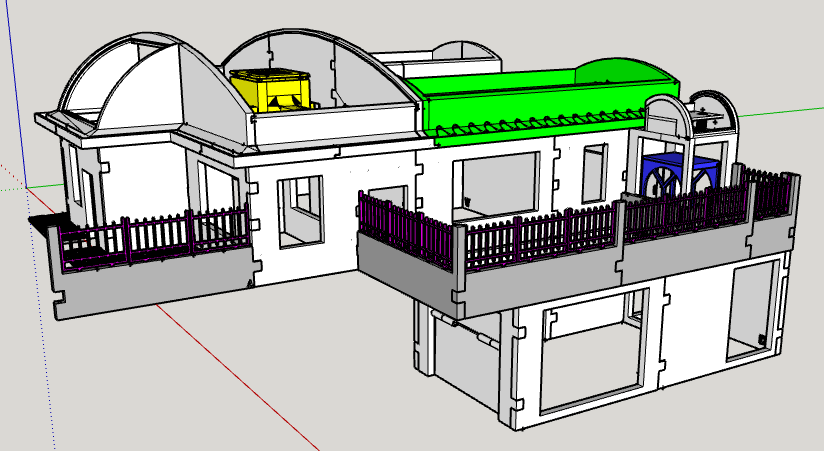
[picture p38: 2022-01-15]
Imatges/CasaFinalAgost.png

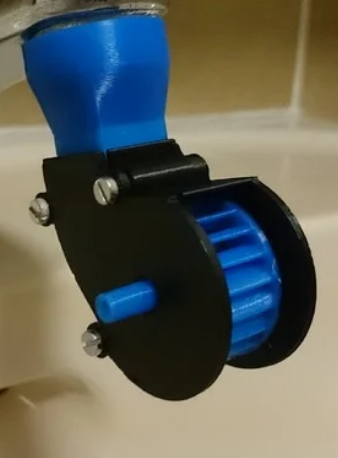
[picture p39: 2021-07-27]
STL_SMARTHOME/Jardi/TurbinaAigua/water turbine.png

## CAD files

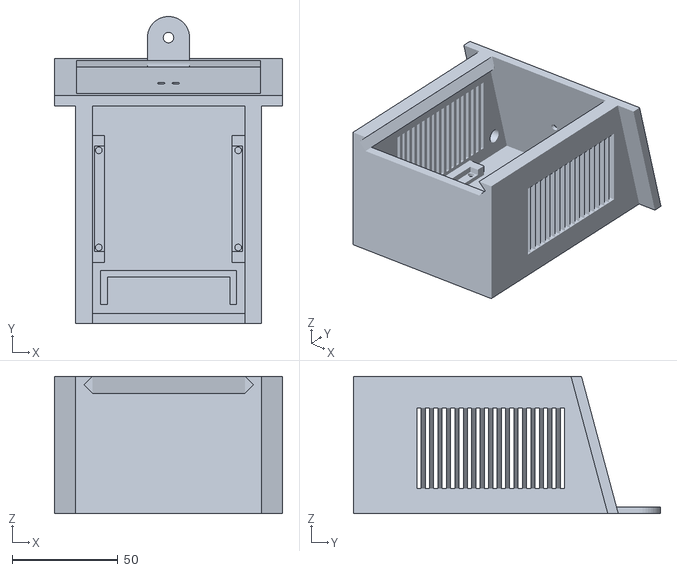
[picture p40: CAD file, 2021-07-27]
STL_SMARTHOME/Jardi/SolarWeather/main-body.stl
108.0 x 145.4 x 65.0

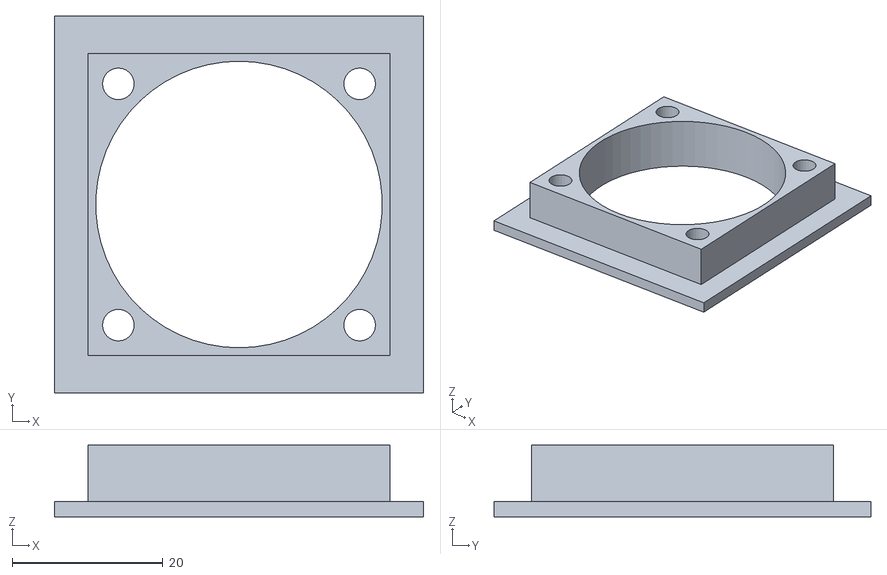
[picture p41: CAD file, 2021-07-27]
STL_SMARTHOME/Casa/AireCondicionat/AireCondicionatTapaMotorC.stl
49.0 x 50.0 x 9.50

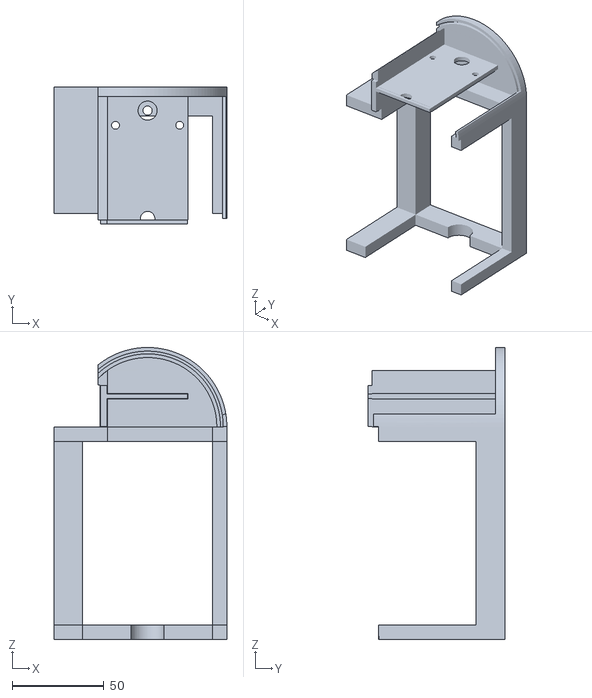
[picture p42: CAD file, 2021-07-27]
STL_SMARTHOME/Casa/Ascensor/Ascensor1B_Motor.stl
94.2 x 74.5 x 159.2

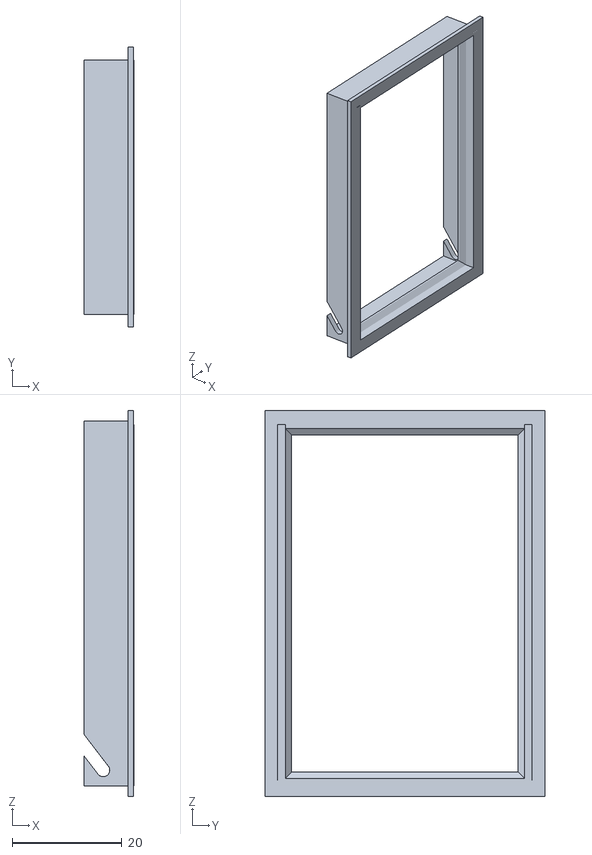
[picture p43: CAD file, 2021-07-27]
STL_SMARTHOME/Casa/Finestres/MarcFinestraCuina.stl
9.06 x 51.0 x 70.3

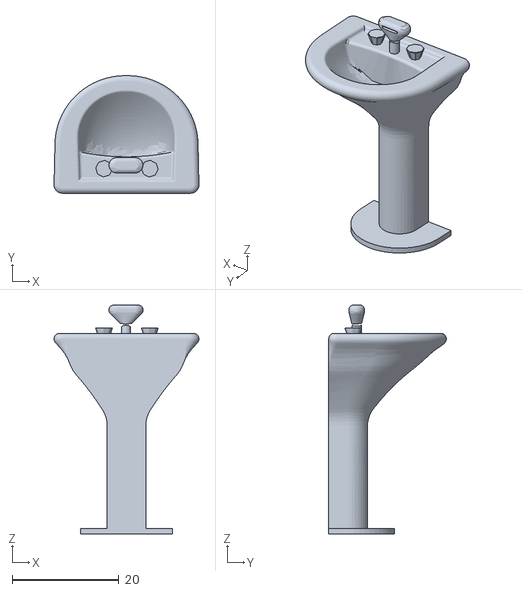
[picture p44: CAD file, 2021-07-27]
STL_SMARTHOME/Casa/Mobiliari/Bany/Lavabo.stl
27.2 x 22.1 x 43.0

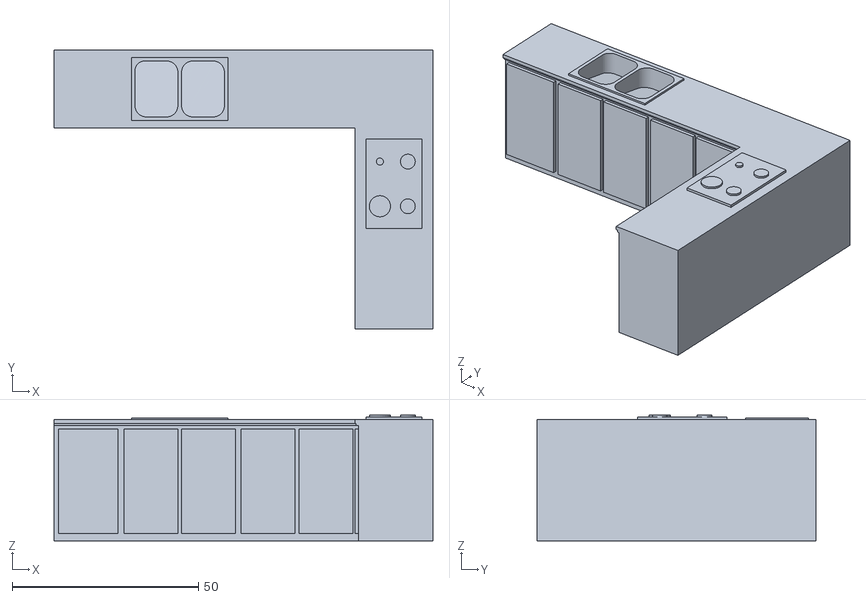
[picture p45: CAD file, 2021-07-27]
STL_SMARTHOME/Casa/Mobiliari/Cuina/MobleCuina.stl
101.8 x 75.0 x 33.7

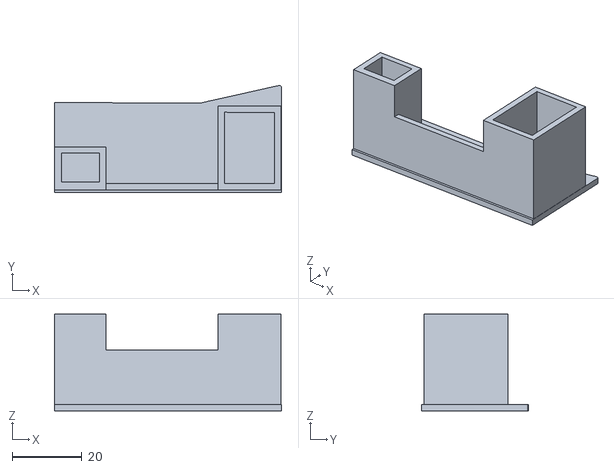
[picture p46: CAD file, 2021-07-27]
STL_SMARTHOME/Casa/Mobiliari/Dormitoris/Escriptori.stl
65.0 x 30.6 x 27.6

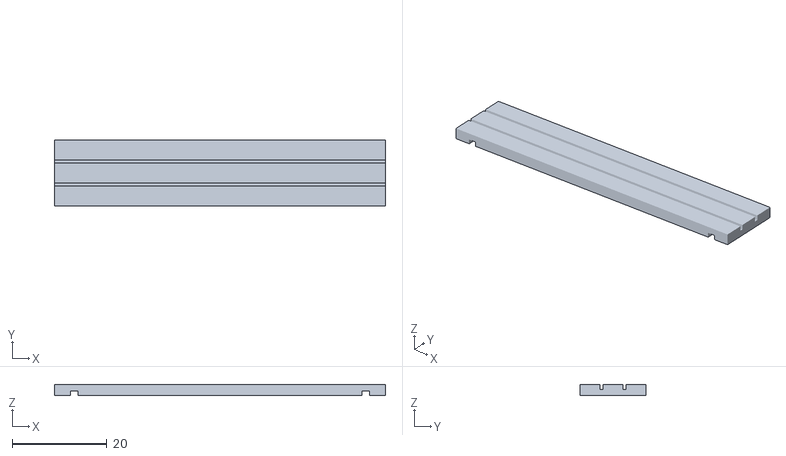
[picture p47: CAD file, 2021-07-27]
STL_SMARTHOME/Casa/Mobiliari/Exterior/TaulaSeients2.stl
70.0 x 14.0 x 2.40

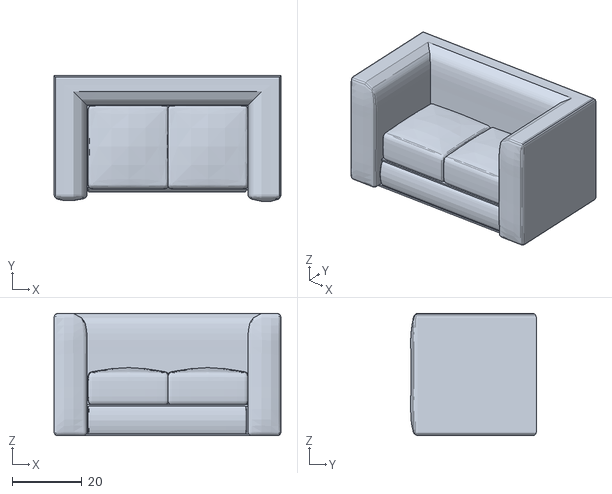
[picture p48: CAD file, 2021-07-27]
STL_SMARTHOME/Casa/Mobiliari/Salo/Sofa2.stl
65.0 x 36.0 x 35.1

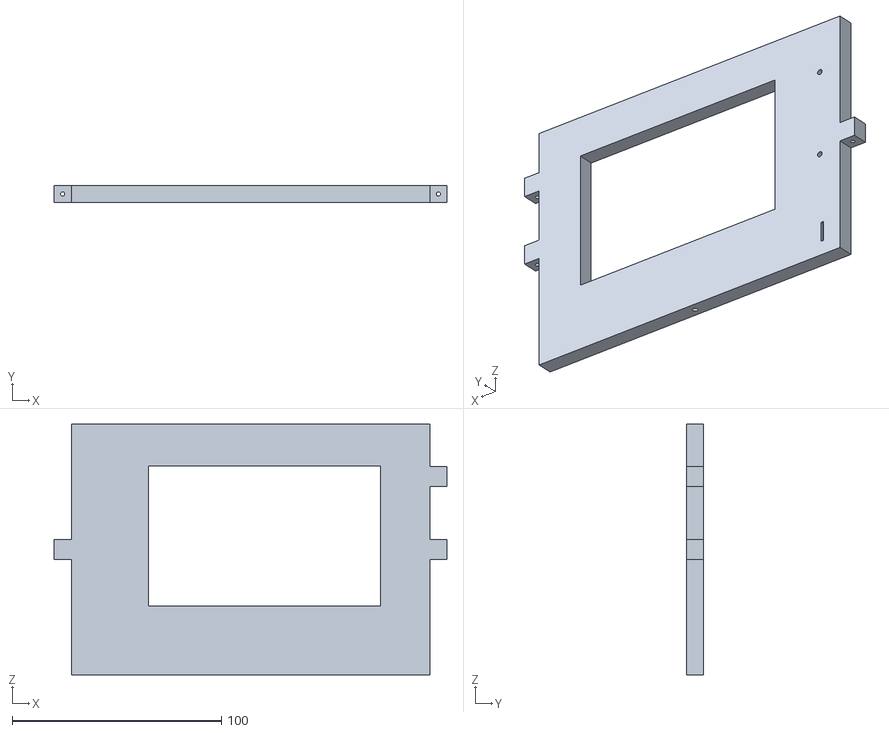
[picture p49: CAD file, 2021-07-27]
STL_SMARTHOME/Casa/Parets/ParetI.stl
188.0 x 8.00 x 120.0

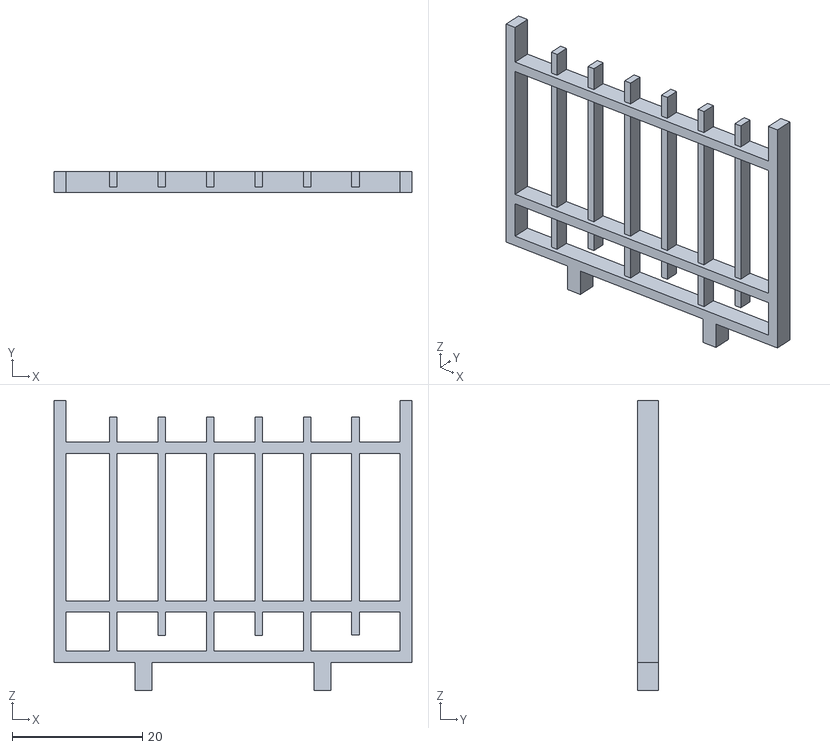
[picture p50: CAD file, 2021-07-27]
STL_SMARTHOME/Casa/PatiGaratge/ReixaMur.stl
54.9 x 3.23 x 44.5

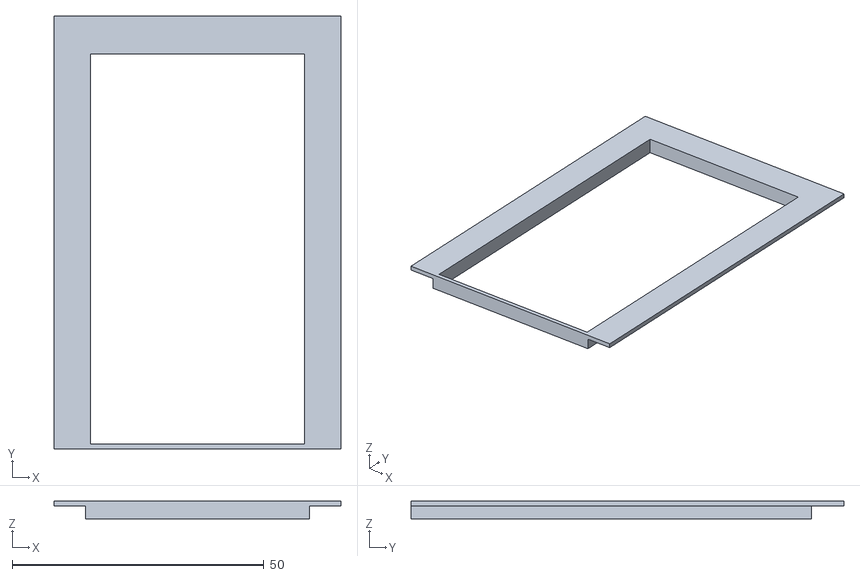
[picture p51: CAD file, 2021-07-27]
STL_SMARTHOME/Casa/Portes/MarcPorta.stl
57.0 x 86.0 x 3.50

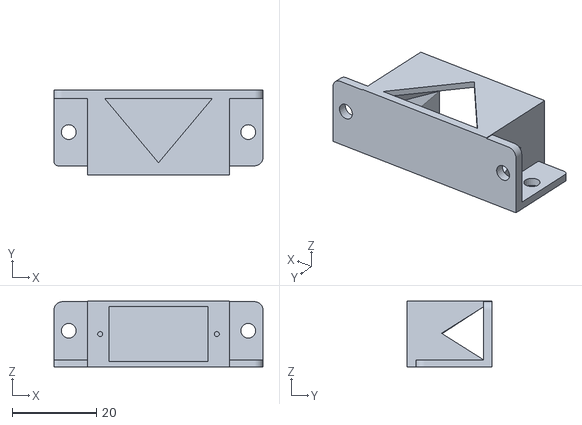
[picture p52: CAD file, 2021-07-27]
STL_SMARTHOME/Casa/ServoSuport.stl
49.6 x 20.2 x 15.6

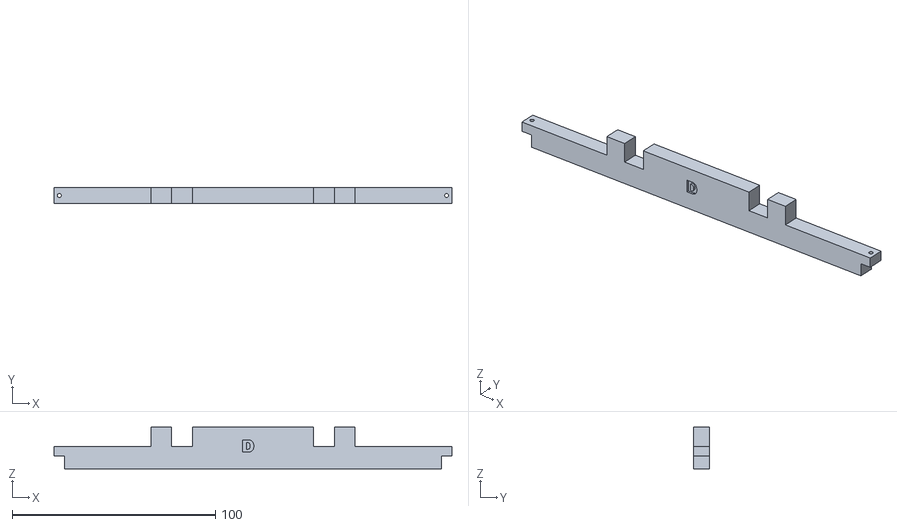
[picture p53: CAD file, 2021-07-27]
STL_SMARTHOME/Casa/Teulada/Suport_Teulada Frontal/SuportTeuladaD.stl
196.0 x 7.75 x 20.5

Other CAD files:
STL_SMARTHOME/Casa/Teulada/Teulada Frontal/TeuladaFrontal_a_transparent2.stl
STL_SMARTHOME/Casa/Teulada/Teulada Posterior/TeulatVerdD2.stl
STL_SMARTHOME/Casa/Teulada/TubDesaiguaCurb.stl
STL_SMARTHOME/Casa/Vorera/VoreraEsquerraPedres3.stl
STL_SMARTHOME/Casa/AireCondicionat/AireCondicionatC.stl
STL_SMARTHOME/Casa/AireCondicionat/TapaAireD.stl
STL_SMARTHOME/Casa/AireCondicionat/TubAireE.stl
STL_SMARTHOME/Casa/AireCondicionat/TubAireF.stl
STL_SMARTHOME/Casa/AireCondicionat/TubEsquerraA.stl
STL_SMARTHOME/Casa/AireCondicionat/TubEsquerraB.stl
STL_SMARTHOME/Casa/Ascensor/Acoblador.stl
STL_SMARTHOME/Casa/Ascensor/Ascensor1A_Motor.stl
STL_SMARTHOME/Casa/Ascensor/Ascensor2.stl
STL_SMARTHOME/Casa/Ascensor/CabinaAscensor.stl
STL_SMARTHOME/Casa/Ascensor/CabinaAscensorTapa.stl
STL_SMARTHOME/Casa/Finestres/MarcFinestraGran.stl
STL_SMARTHOME/Casa/Finestres/MarcFinestraPetita.stl
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
